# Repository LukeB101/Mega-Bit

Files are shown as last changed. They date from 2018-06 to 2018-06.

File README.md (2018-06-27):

# Mega-Bit
Imperial College London Electrical and Electronic Engineering 3rd year project for the Micro:Bit community

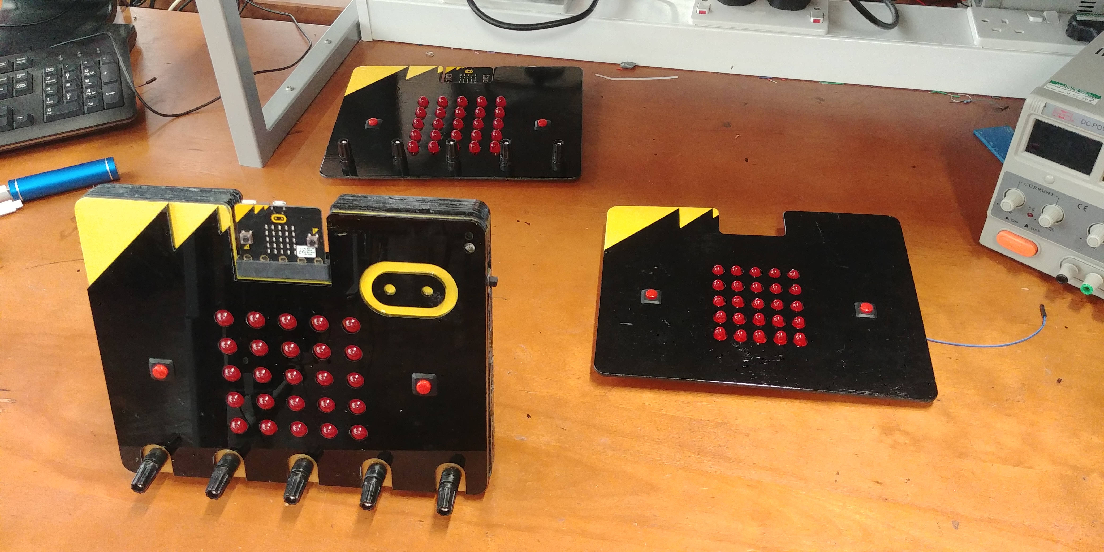
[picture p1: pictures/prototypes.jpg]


The project aim was to create a teaching aid to assist with using the BBC micro:bit to teach programming in schools. To do this it must replicate all of the student's work on a larger scale for the whole class to see. It should do this with no impact on the student's code, simply plug the student's micro:bit in and watch!

## Repository structure:

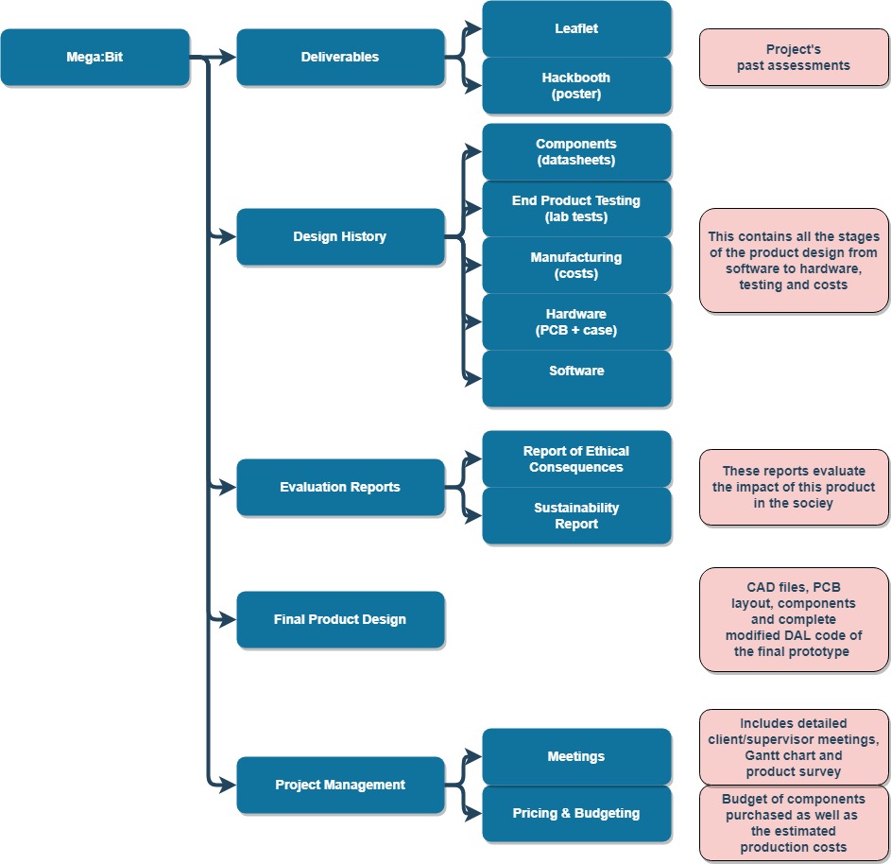
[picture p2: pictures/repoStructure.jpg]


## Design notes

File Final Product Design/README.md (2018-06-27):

This folder contains all files used in the final design. This includes CAD files, component cost breakdown and a complete modified-DAL.

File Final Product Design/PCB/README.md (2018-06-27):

Final PCB designs

Files are duplicates from [Design History  /  Hardware  /  PCB  /  MEGABIT FINAL PCB](https://github.com/LukeB101/Mega-Bit/tree/master/Design%20History/Hardware/PCB/MEGABIT%20FINAL%20PCB)

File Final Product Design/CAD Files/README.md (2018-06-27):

All files to replicate our 3D acrylic case.

Files are duplicates from [Design History  /  Hardware  /  Prototype Modelling  /  Acrylic 3D Final Prototype](https://github.com/LukeB101/Mega-Bit/tree/master/Design%20History/Hardware/Prototype%20Modelling/Acrylic%203D%20Final%20Prototype)

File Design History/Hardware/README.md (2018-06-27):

The hardware of this project is split into two categories; the PCB and the prototype modelling of the mega:bit case.

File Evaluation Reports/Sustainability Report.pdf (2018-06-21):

## Sustainability Report

Aim

This report aims to measure the social and environmental impact of the mega:bit and address future goals and areas of improvement in this area.

Environmental Impact

Environmental consciousness in the production, distribution and subsequent usage of mega:bit is a crucial concern. It is important to ensure that the usage of power, materials and resources in creating this product is justified and that it is made in a responsible manner with reduced wastage. However, since mirco:bit is a not-for-profit organization that serves for educational purposes, affordability for every student is also vital. Therefore, a balance must be made in considering low-cost options as well as environmentally friendly methods.

Production Considerations

The mega:bit is designed to be sent to mass production with 5000 units initially with a potential market of 100,000 units. Consequently, it is important to keep it as environmentally-friendly as possible, reducing damaging and unsafe resources. To make the product more sustainable several points were considered when designing it:

- Materials Wastage: Creating the product entirely as a printed PCB would result in copper wastage as there would be some unused space. However, this would be more practical for production and usage as an additional step of complex wiring and assembly would be reduced minimizing human resources. The plastic outer covering will be also mass produced and by keeping the design unchanged a single mold will be used reducing cost as well as metal wastage.
- Shipping: Although outsourcing production of PCBs and plastic molds is greatly cheaper, rooting manufacturing in the UK is more sustainable. This reduces the carbon footprint associated with cargo shipping from overseas massively. The quotes prices in the UK were checked to be within the preplanned budget.
- Recyclable Materials: The plastic case will be made from a thermoplastic, ¹ which is in nature recyclable. PCBs are also recycled by certain companies.

1
“3 Words: Recyclable Thermoset Plastics.” Nanalyze, 23 Feb. 2017, www.nanalyze.com/2017/01/recyclable-thermoset-plastics/. (http://www.nanalyze.com/2017/01/recyclable-thermoset-plastics/)

Product Usage Considerations

It is also important to ensure power consumption is minimal when mega:bit is used in schools.

- Power Options: In order to reduce wastage with non-rechargeable batteries, mega:bit offers powering with USB ports (portable chargers) or directly connecting to power sockets. To ensure teachers have flexibility in power options, 9V battery port is also included. However, they will be informed in the instruction manual to dispose used batteries responsibly.
- Components Choices: Power efficiency was taken into account in the product design and component choices. For example, a Buck converter was chosen for stepping down voltage instead of a linear regulator due to lower power consumption.
- Long-term Usage: Mega:bit is designed to be robust and durable in a classroom set-up without need for constant replacement. The outer plastic case protects the product from damage from handling by children and falls.

Areas for Improvement

- Recycled Plastic: In the subsequent productions, the larger number of units manufactured might reduce costs such as prices of components due to economies of scale. This could give some leverage to invest in using recycled plastic instead for the outer case.

Social Impact

The micro:bit foundation has a leading role to play in kindling interest in coding amongst children and developing a generation of tech pioneers. Mega:bit will serve a major role in enabling this process by enhancing the learning experience for children and being an effective companion for teacher to create a stimulating learning environment.

Educational Benefits

- Promotes Collaboration: Micro:bit is already being used by thousands of students in the classroom but the mega:bit allows for easy demonstration and sharing of work and ideas among children. This fosters teamwork and the quality of learning from one another.

Inclusion Benefits

- Cater to Special Needs: Beyond being used as a demonstration tool, individuals with special needs can use mega:bit as a complementary tool with their micro:bit. The larger display helps those with partial sight or low vision to code more easily ensuring micro:bit remains an inclusive device for coding.

Future Work

- Haptic Feedback: A possible extension discussed with the client was having haptic feedback. Instead of LEDs, tactile buttons can be configured to enable micro:bit to be used in existing coding programs for the blind.

Conclusion

The mega:bit reinforces micro:bit's position as a useful and inclusive educational tool for computer education. The Micro:bit Educational Foundation has had massive positive impact globally on teaching coding and is continuing to expand in developing countries. The mega:bit would be a versatile tool that would complement and enhance the learning process with the micro;bit reaping more benefits. In future releases, there could be more research into using recycled materials and reducing carbon footprint in an affordable manner.

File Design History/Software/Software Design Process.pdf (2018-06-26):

# Software Design Process

## Objective

Create a method to display student's code from their micro:bit onto a larger mega:bit for demonstration without affecting the micro:bit's performance. This must be done while taking into account the sensors and interactions with additional features such as radio communication. This has to be implemented in a manner such that any student's work can be displayed simply onto the mega:bit's LED matrix without need for additional coding or soldering from the teacher or student.

## Design Context and Software Stack

Several layers exist to translate the user code down to the hardware level. Each ‘sits’ on the top of the next and is procedurally stepped down to the hardware control. However, in some cases, mbed, DAL, and microPython can access the hardware directly. We will concentrate on the online MakeCode editor which differs from the diagram to the left. Instead of the MicroPython layer there are two different layers which connect the user code to the DAL which are

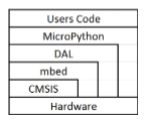
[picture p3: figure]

called the 'pxt-microbit' and 'microbit' layers. Examples of code being translated through the software stack are at Appendix A.

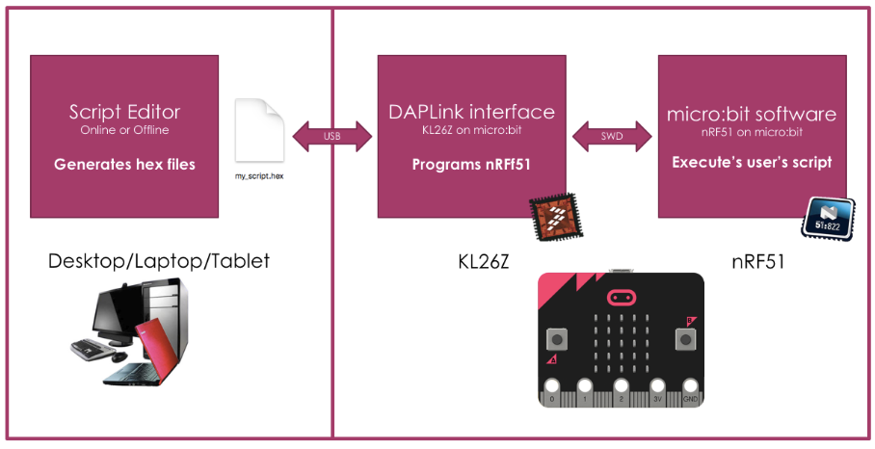
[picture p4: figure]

The micro:bit runtime or device abstraction layer (DAL) contains all the hardware drivers for the micro:bit such as display, radio etc and runtime mechanisms that allow flexible programming of the micro:bit. The script editor generates the .hex files which are then uploaded to the micro:bit to be programmed and executed. The script editor combines the user code with the DAL to form the .hex files. We will insert our code here as it will apply to all user code formats.

## Design Selection Process

1) Accessibility Pin: One of the GPIO pins (p12) is a marked as a ‘reserved accessibility pin’ which by default is not accessible to the user. This was created to leave the Micro:Bit Foundation the option for expansion modules. The theory was for any future peripherals which required data communication this pin would provide a UART connection for data transfer. The Mega:Bit suits this function perfectly.
2) Neopixels: These are addressable multicoloured LEDs that are supported by the micro:bit neopixel library. They can be attached simply with 3 crocodile clip connections for data input, power and ground. A large number of neopixels cannot be powered by the micro:bit and need to be powered externally. The brightness of every LED can be adjusted independently in the software. These could be used for the mega:bit's display however they require strict timings which would require the use of interrupts. This has the potential to interfere with other low level activity on the micro:bit which also require strict timings and interrupts (for example the Bluetooth and RF radios).
3) I2C: The larger LED matrix could be controlled via I2C communication. An I2C LED display driver could be used to drive a matrix of LEDs which would be simple to implement as I2C is natively supported. I2C also has less strict timing requirements as the master can drive the clock at any frequency it would like (up to 400 kHz) in fact if the master has background tasks to do while transmitting it can 'stretch' the clock signal to greater allow for these. I2C bus utilisation must be investigated as we do not want to interfere with the other sensors on the I2C bus.
4) USB: Possibly provide two-way communication to control the mega:bit through the USB port or ‘clone’ the code onto the mega:bit. Two-way communication through the USB port is not feasible but cloning the code potentially is. The code is stored in a particular place in the on-chip memory which could be read and copied to the mega:bit. This however requires a level of 'intelligence' on the mega:bit side, for instance like a Raspberry Pi. This would obviously add cost and be more expensive than the alternative methods.

## Execution of I2C Method

The I2C method was chosen as it provides the simplest and cleanest solution however the accessibility pin may still be used to provide a handshake to confirm when the micro:bit is plugged into the mega:bit.

Micro:Bit I2C Functionality

The I2C communication standard allows for many I2C slaves. The micro:bit has two existing devices on the I2C bus, the compass and accelerometer, we must ensure our use of the bus does not affect the existing functionality. This is done by ensuring there are no addresses clashes with the existing sensors. (See Appendix B for I2C address selection)

It is important to note that the 7-bit addresses found in the device datasheets have to translated with a binary shift left as an 8-bit address is to be used with the micro:bit. For example, the adafruit HT16K33 backpack has an address 0x70, that must be translated to 0xE0.

Driving LED Matrix using I2C

Components used: Adafruit 0.8" 8x8 Matrix with HT16K33 Backpack, micro:bit edge connector.

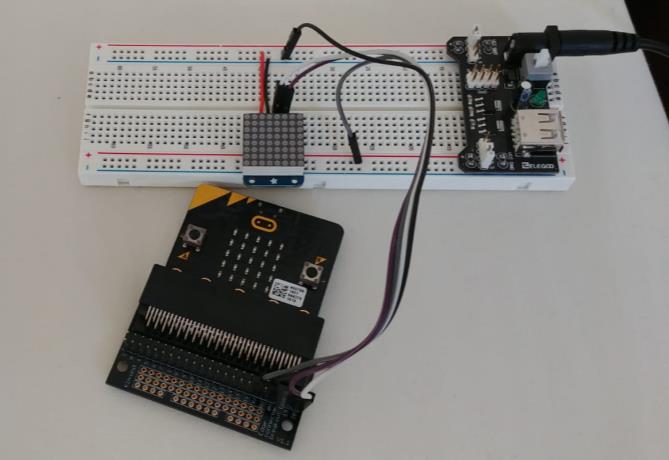
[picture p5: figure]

An Adafruit backpack¹ was used for convenience as a comprehensive library exists. This means we can quickly and easily create a proof of concept before moving on to creating our own PCBs. The I2C pins of the micro:bit, pin 19 and 20 are accessed using an edge connector. The connections are made as follows:

Microbit Pin | Backpack Pin
Pin 19 | SCA
Pin 20 | SDA
GND | GND
3V | VCC+

The DAL (Device Abstraction Layer) code was modified in order to implement the communication with the I2C external LED matrix.

The listing below shows the initialisation of the global variables needed to set up the LED display. The general structure of the code to interface with the HT16K33 LED driver was translated to C++ from a Python library for the backpack

2

1 Microbit Playground. (2016). Control a 8x8 LED matrix with an I2C backpack on the microbit. [online] Available at: https://microbit-playground.co.uk/components/8x8-matrix-HT16K33-microbit.

2
https://bitbucket.org/thesheep/microbitht16k33/src/a5b7961f0b57ba226ab98edc2c5f8d95d8954d00/ht16k33.py

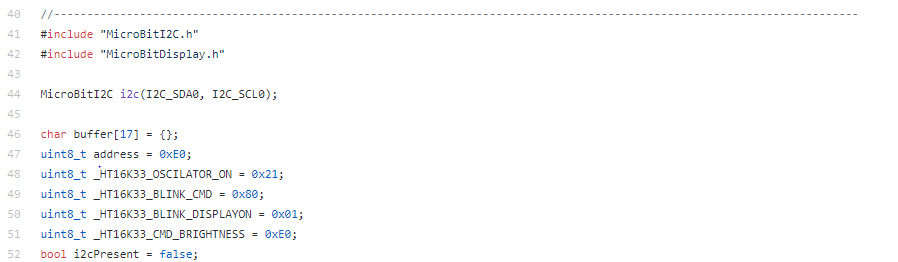
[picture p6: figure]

Configuring Display on LED Matrix

The listing below shows the initialisation process of the LED display. After having checked whether the I2C ports are being used (i.e. if a mega:bit is connected), the buffer is filled with zeroes, the oscillator is turned on and an initial blink rate and brightness are set.

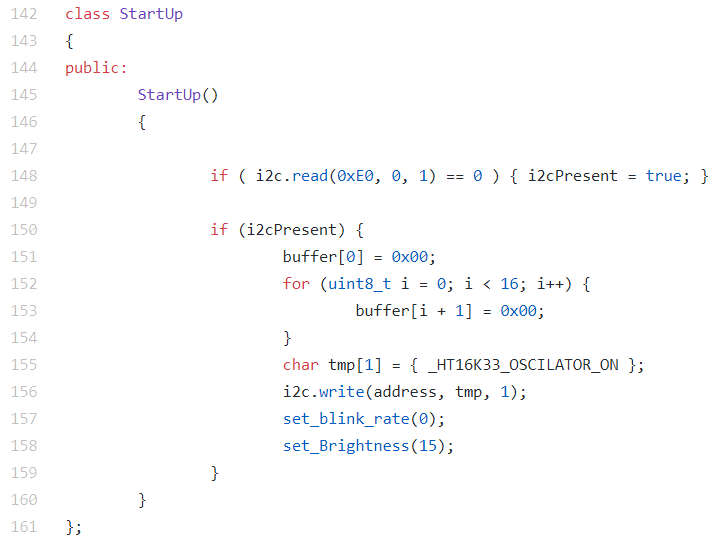
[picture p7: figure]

Eight main display control functions have been implemented:

Function | Description
set_blink_rate | Sets the blink rate of the display
set_Brightness | Sets the brightness of the display
update_Brightness | Updates the brightness of the display to a new value
fill | Fills the display
initialise | Initialises the display (similar to the StartUp class above)
_pixel | Plots single pixels on the matrix
pixel | Converts x coordinates and calls _pixel function
bufferClear | Clears the buffer

Replicating All Functionality

The micro:bit display is updated to match a 'buffer' which stores the image/text to be displayed. It works on an interrupt basis and is updated several times per second. The I2C display holds the previous state so does not need to be constantly updated, this would also take up unnecessary processing power and bus utilisation. Therefore, we only update the I2C display whenever the buffer is modified, this is the most efficient way of implementing the code.

## Additional Work

After successfully implementing the Adafruit LED backpack we moved to developing custom PCBs, these used the same HT16K33 chips so the software was unaffected.

Handshake
A simple handshake was then implemented; using a 555 timer a 1kHz square wave is supplied to the accessibility pin of the micro:bit. When the microbit is powered up, it senses the presence of the square wave on its accessibility pin. If there is no 1kHz signal, the micro:bit will function as per usual. However, if it is present, a boolean variable is set to true and thus whenever the buffer is edited, through an if statement, the I2C display is also updated. This means that extra processing power is not used to send I2C commands when the micro:bit is not plugged into the mega:bit. This can also be adapted to function as an identifier, different signal frequencies indicating different peripherals.

IS31FL3737
As explained in the hardware section of the GitHub repository (found at https://github.com/LukeB101/Mega-Bit/tree/master/Design%20History/Hardware) after implementing all functionality described above, we investigated using a different chip which runs off 3.3V rather than 5V and allows for other functionality. This chip requires different code which is still under development as the custom PCB did not arrive in time to write the software before university deadlines. This software will be developed outside of this university project.

Further References:

"Microbit-RTCC-MCP7941X - Program To Interface Bbc Microbit To A MCP79410... | Mbed".
Os.Mbed.Com, https://os.mbed.com/users/euxton/code/microbit-RTCC-MCP7941X/file/92208e3aae5a/main.cpp/.

"Driving Adafruit I2C 8X8 LED Matrices With The BBC Micro:Bit". Smythe-Consulting.Com, 2017, http://www.smythe-consulting.com/2017/03/driving-adafruit-i2c-8x8-led-matrices.html.

Micro:Bit DAL: https://github.com/lancaster-university/microbit-dal

Micro:Bit Software Stack: https://github.com/lancaster-university

## Appendix A

Using the JavaScript editor at makecode.microbit.org

The different headings show different layers in the software stack

JavaScript

Taking the code:

basic.showNumber(0)

Pxt-microbit
This is first translated by pxt-microbit/libs/core/basic | void | showNumber(int | value, | int | interval =
150) {

https://github.com/Microsoft/pxt-microbit/blob/master/libs/core/basic.cpp#L19

(as number does not need scroll) in to: | uBit.display.printChar(t.charAt(0), interval * 5);
uBit is defined in pxt.cpp: | MicroBit | uBit;

https://github.com/Microsoft/pxt-microbit/blob/master/libs/core/pxt.cpp#L4

microbit
This is passed to the DAL wrapper where the display class is defined: MicroBitDisplay
display;

https://github.com/lancaster-university/microbit/blob/master/inc/MicroBit.h#L111

microbit-DAL
This is passed to the DAL where the printChar function is defined:

https://github.com/lancaster-university/microbit-dal/blob/master/source/drivers/MicroBitDisplay.cpp#L606 (https://github.com/lancaster-university/microbit-dal/blob/master/source/drivers/MicroBitDisplay.cpp)

The printChar function calls the printCharAsync function: | this->printCharAsync(c,
delay);

Which is defined here:

https://github.com/lancaster-university/microbit-dal/blob/master/source/drivers/MicroBitDisplay.cpp#L481 (https://github.com/lancaster-university/microbit-dal/blob/master/source/drivers/MicroBitDisplay.cpp)

The printCharAsync function calls the image.print function: | image.print(c, 0, 0);

Which is defined here:

https://github.com/lancaster-university/microbit-dal/blob/master/source/types/MicroBitImage.cpp#L572 (https://github.com/lancaster-university/microbit-dal/blob/master/source/types/MicroBitImage.cpp#L572)

and calls: this->getBitmap()[y1*getWidth()+x1] = (v & (0x10 >> col)) ? 255 : 0;

Conclusion
From this and other examples it is clear our software edits must be done within the MicroBitImage.cpp file since this is at the lowest level and deals with the buffer.

## Appendix B

## Adafruit I2C Sensor Addresses

To investigate the possibility of I2C address clashes a table was created displaying I2C sensors on the market and their addresses. Adafruit and SparkFun were chosen specifically as our client indicated any sensors used in schools would be used in a breakout board package and that these are the market leaders.

The table below and the i2c-addresses.pdf file show the range of I2C addresses used in their sensors. This data will be used to ensure the Mega:Bit does not clash with many, if any, other devices.

For the IS31FL3737 the address 0xAA was chosen, in 7bit format that is 0x55 which is taken by only one device which has 7 selectable address therefore does not pose any major risk of device clashes.

Sensor | I2C address | Webpage link
TCA9548A I2C Multiplexer | 0x70 (but can be adjusted from 0x70 to 0x77) | https://www.adafruit.com/product/27 17 (https://www.adafruit.com/product/2717)
Adafruit I2C Controlled + Keypad Shield Kit for 16x2 LCD | 0x20 | https://www.adafruit.com/product/71 5 (https://www.adafruit.com/product/715)
FLORA Accelerometer/Compass Sensor - LSM303 - v1.0 | 0x32 & 0x3C | https://www.adafruit.com/product/12 47 (https://www.adafruit.com/product/1247)
Flora Lux Sensor - TSL2561 Light Sensor - v1.0 | 0x39, 0x29, 0x49 | https://www.adafruit.com/product/12 46 (https://www.adafruit.com/product/1246)
MCP9808 High Accuracy I2C Temperature Sensor Breakout Board | Uses any I2C address from 0x18 thru 0x1F | https://www.adafruit.com/product/17 82 (https://www.adafruit.com/product/1782)
Adafruit HTU21D-F Temperature & Humidity Sensor Breakout Board | 0x40 | https://www.adafruit.com/product/18 99 (https://www.adafruit.com/product/1899)
Adafruit Blue&White 16x2 LCD+Keypad Kit for Raspberry Pi | 0x20 | https://www.adafruit.com/product/11 15 (https://www.adafruit.com/product/1115)

LCD Shield Kit w/ 16x2 Character Display - Only 2 pins used! - BLUE AND WHITE | 0x20 | https://www.adafruit.com/product/77 2 (https://www.adafruit.com/product/772)
RGB LCD Shield Kit w/ 16x2 Character Display - Only 2 pins used! - NEGATIVE DISPLAY | 0x20 | https://www.adafruit.com/product/71 4 (https://www.adafruit.com/product/714)
MaximIntegrated DS1307 – real time clock | 0x68
Melexis MLX90614 – infrarred thermometer | 0x5A
FreeScale MMA8452Q 3-Axis Accelerometer | 0x1C, 0x1D
AKM AK9753 IR Sensor | 0x64H, 0x65H, 0x66H
AM2315 - Encased I2C Temperature/Humidity Sensor | 0x5C | https://www.adafruit.com/product/26 51 (https://www.adafruit.com/product/2651)
Adafruit BMP280 I2C or SPI Barometric Pressure & Altitude Sensor | SPI avoid i2c address collisions | https://www.adafruit.com/product/26 51 (https://www.adafruit.com/product/2651)
Adafruit Mini 8x8 LED Matrix w/I2C Backpack -Ultra Bright White | between 0x70-0x73 | https://www.adafruit.com/product/10 80 (https://www.adafruit.com/product/1080)
Adafruit Bicolor LED Square Pixel Matrix with I2C Backpack | between 0x70-0x77 | https://www.adafruit.com/product/90 2 (https://www.adafruit.com/product/902)
Adafruit 16-Channel 12-bit PWM/Servo Driver - I2C interface - PCA9685 | between 0x40-0x7F | https://www.adafruit.com/product/81 5 (https://www.adafruit.com/product/815)
Adafruit 16-Channel 12-bit PWM/Servo Shield - I2C interface | between 0x60-0x80 | https://www.adafruit.com/product/14 11 (https://www.adafruit.com/product/1411)
ADXL345 - Triple-Axis Accelerometer (+-2g/4g/8g/16g) w/ I2C/SPI | 0x53 | https://www.adafruit.com/product/12 31 (https://www.adafruit.com/product/1231)

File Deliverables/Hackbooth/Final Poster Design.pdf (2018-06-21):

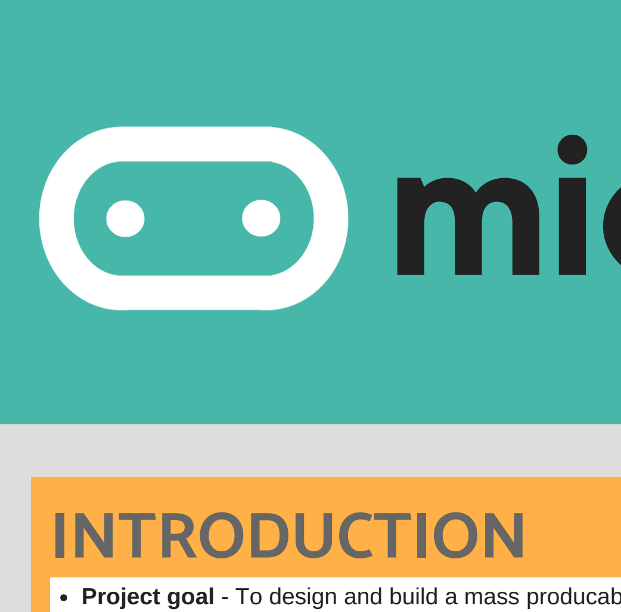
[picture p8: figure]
INTRODUCTION

# micro:bit to mega:bit

# A TEACHING TOOL TO ENHANCE COMPUTING EDUCATION IN SCHOOLS

</>

Project goal - To design and build a mass producable teaching aid for schools to help with incorporating micro:bit into computing lessons.

Current Problem- The micro:bit is a pocket-sized handheld computer with a programmable LED display. While the small micro:bit is great for coding, teachers find it difficult to demonstrate student's work to the whole class.

Haptic Feedback: Replacing the LED matrix with tactile feedback to enable visually impaired students to use the micro:bit RGB LEDs: Switch between colours of the LED matrix for improved learning experience
Foldable Handles and stand: For easy use and storage for teachers
Changing the I2C address: Enable usage of all peripherals without possibility of I2C addresses conflicting

# FUTURE WORK

# BACKGROUND

Our client, Micro:bit Educational Foundation, is a not-for-profit organisation that created the micro:bit to encourage digital creativity and develop a new generation of tech pioneers.

It is rapidly expanding globally and being used in diverse settings such as refugee camps in Greece.

1 Million Students | 22 Countries

While designing the mega:bit, important client criteria and requirements had to be taken into account in order to make a device that is easy to handle for the teacher and is suitable for use in schools.

1) Ergonomic Design
2) Easy to Use
3) Safe

# CLIENT CRITERIA

Display: The mega:bit replicates the form factor of the micro:bit with a 5x5 LED display, two push buttons and edge connectors at the bottom, but is much larger allowing the whole class to see the operation of the code.
Whenever there is a change in the LED display of the micro:bit, the larger LED matrix of the micro:bit is updated via I2C communication.

Seamless Integration: The student's micro:bit is plugged into the top of the mega:bit without the need for any additional soldering or coding from the user's side which allows for easy use.

Detection of Micro:bit: A "handshake" between the mega:bit and micro:bit allows detection for when a micro:bit is plugged in.

Battery Indicator: Features such as battery level indicators and a reset button are also present for convenience.

# SOLUTION

# PRODUCTION

The mega:bit will be released in batches in the UK first. It will then expand globally as the micro:bit community grows.

Unit Price | Initial Volume

£50

mega:bit will be mass-produced in two parts: a PCB and a plastic outer casing. A medium sized PCB is used as it is low cost in large numbers. To ensure robustness in a classroom environment, the casing will conceal and protect the electronic components from droppage and static.

Potential Market

5000
units | units

100k

micro:bit official webpage: microbit.org
prototyping: https://www.adafruit.com/product/870
battery indicator: http://www.instructables.com/id/9v-battery-status-indicator-circuit/

# BIBLIOGRAPHY

Microbit.org. (n.d) Micro:bit Educational Foundation. [online] Available at: http://www.microbit.org/.
Industries, A. (2018). Adafruit Mini 8x8 LED Matrix w/I2C Backpack -Red. [online] Adafruit.com.
Available at: https://www.adafruit.com/product/870.
Instructables.com. (2012). 9v Battery Status Indicator Circuit. [online] Available at: http://www.instructables.com/id/9v-battery-status-indicator-circuit/.
GitHub. (n.d.). BBC micro:bit. [online]
Available at: https://github.com/bbcmicrobit.

Hardware: Price, S., Boskovic, K.,Christodoulou, A., Lu Chen, W. Software: Bussell, L., Carrani, J., Mathivanan, A.
Academic Supervisor: Stott, E.
Client Supervisor: Austin, J.
Department of Electrical and Electrical Engineering, Imperial College London SW7 2AZ

More powerful LED driver, able to drive up to 144 LEDs and provide individual brightness USB or 9V Battery power =
Buck 3.3V, linear regulator 5V Battery indicator

Final 100 x 120 PCB, 10 mm LEDs

## Final PCB Design

Stage 1 | Stage 2 | Stage 3 | Stage 4

62 x 57mm PCB size, 3 mm LEDs

## Test I2C Functionality

90 degree micro:bit edge
connector
LED matrix controlled by LED driver
Power supply: 5V USB followed by 3.3V linear regulator

### 1. I2C option – use micro:bit’s I2C

serial interface to connect mega:bit as a slave device

### 2. Accessibility pin option – Use pin

reserved for transfering data using UART
Result: I2C chosen as it is simple and effective. Other I2C devices can still be connected in parallel

## Data Transfer Methods

2 LED PWM drivers to enable LED brightness control

### 4 x 1.5V battery - buck to 3.3V

96 x 66mm PCB size, 10 mm LEDs

## Individual Brightness

Added possibility to choose between USB and batteries. 9V battery - 5V linear regulator +3.3V linear regulator

### 2 x 1.5V battery - boost to 5V

+3.3V linear regulator

100 x 74mm PCB size, 8 mm LEDs

## Powering Options

### 1. Alter the print functions in the

DAL to include mega:bit display print code via I2C

### 2. Take into account the mega:bit’s

LED matrix driver dimensions by coding correct image bitmaps

### 3. Mega:bit LED matrix updated

every time there is a change in the micro:bit’s display
Result: Single letters can be displayed on matrix

## I2C Implementation

### 1. Alter animation mode in the DAL

to allow for functions such as scroll and rotation of text.

### 2. Enable control of individual LED

brightness on the mega:bit Result: All characters, images and scrolling of text can be displayed on the mega:bit with specified brightness

## Animation Mode

Use accessibility pin to detect when micro:bit is connected with a predefined signal that the micro:bit searches for on startup.

### micro:bit Detection

# Software

# Hardware

# Final Product

Rev. 1 | Physical model

# Rev. 2

Buttons

micro:bit Slot

Handle

Plastic Front Cover

PCB

Plastic Back Cover

Banana Connectors

LED Matrix

# Block Diagram

# Prototype

4) Reliable
5) Sustainable
6) Cost-Effective

Plastic Front & Back Case
PCB
Assembled by the end user with simple screws
Instruction Manual included

## mega:bit

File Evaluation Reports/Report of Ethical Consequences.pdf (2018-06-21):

## Report of Ethical Consequences

Aim

The aim of this report is to examine the ethical considerations associated with the design, manufacturing, and marketing of the mega:bit product. Ethics in production and marketing of a product are of great significance as non-compliance with ethical principles are undesirable and would harm the company's reputation.

The micro:bit Foundation

The micro:bit Foundation is a collaboration of more than 30 international organisations, pioneering start-ups and transformative education organisations. It is a not-for-profit organisation with an aim to make computing more interesting, and accessible to help inspire every child to start coding and make a new generation of tech pioneers. The micro:bit is a pocket-sized programmable computer with motion detection, a built-in compass and Bluetooth technology that has been introduced to over 500 schools in the UK to serve this aim.¹

Micro:bit Foundation's Mission

The mission of the Foundation includes the following²
:
- Enable and inspire all children to participate in the digital world, with a particular focus on girls and those from disadvantaged backgrounds.
- Make micro:bit the easiest and most effective learning tool for digital skills and creativity.
- Work in collaboration with educators to create and curate exceptional curriculum materials, training programs and resources.
- Build and support communities of educators and partners to remove the barriers to learning digital skills.

Furthermore, the Micro:Bit Foundation is also helping change the attitude of many children towards computing by making coding and technology more accessible to them through its ‘Make it Digital’ initiative³ and encouraging more girls into computing subjects. Research conducted after over 1 million devices had already been deployed has shown that⁴
:
- 90% of students said the micro:bit showed them that anyone can code.
- 86% of students said the micro:bit made Computer Science more interesting.

1 BBC. (n.d.). Make It Digital - The BBC micro:bit - BBC. [online] Available at: http://www.bbc.co.uk/programmes/articles/4hVG2Br1W1LKCmw8nSm9WnQ/the-bbc-micro-bit. 2 Microbit.org. (n.d.). About. [online] Available at: http://microbit.org/about/.
3 Microbit.org. (n.d.). Micro:bit Educational Foundation is here!. [online] Available at: http://microbit.org/en/news/news-microbit-foundation/.
4 Microbit.org. (n.d.). Let's make learning with technology fun!. [online] Available at: http://microbit.org/teach/.

- 70% more girls said they would choose Computing as a school subject after using the micro:bit.
- 85% of teachers agree it has made ICT/Computer Science more enjoyable for their students.
- Half of teachers who’ve used the micro:bit say they now feel more confident as a teacher, particularly those who say they’re not very confident in teaching Computing.

To ensure the micro:bit’s aim continues so that more children get involved in coding, mega:bit was designed to further enhance the teaching experience and make lessons more fun and involving for students.

The mega:bit

The mega:bit is a teaching aid for use with the micro:bit. By simply plugging in a student's micro:bit it displays their work on a larger scale. It is designed to allow easy demonstration of students’ work to the whole class and increase the interactive participation of students when using the micro:bit. As a result, the production of the mega:bit will enable the Micro:Bit Foundation to grow responsibly by still fitting into the Foundation’s aim to encourage students, and especially girls, to get more involved in STEM subjects.

Ethical Considerations relating to mega:bit

To fulfill the mission of the Micro:Bit Foundation, the mega:bit has been designed to meet the ethical requirements associated with the environment in which it will be used, i.e. in schools. These are high product quality, safety, ethical pricing strategy and marketing transparency.

Product quality and safety

Following the successful design of the micro:bit, the mega:bit replicates this design making it safe to use in schools. The mega:bit has been rigorously tested to ensure this. The product is also ergonomic as it is designed to be lightweight, sleek and robust. Furthermore, its features meet the specific teacher requirements which were identified through a survey conducted in the teacher channel of the micro:bit community. Finally, the product design comprises a handle for people with disabilities to ensure increased accessibility for users.

Under a limited budget, an important ethical concern was how to design and build a cost efficient product without reducing its quality. This was achieved through thorough research on components and materials to be used and three PCB revisions to test and select the design options to be implemented in the final design and prototype.

Ethical Pricing

The price of the megabit is £50, making it affordable to an average school. The price reflects the cost of production of the mega:bit and includes an added profit margin of £28. This profit margin will primarily be taken by the manufacturing and fabrication companies leaving a much small profit for the Foundation. The potential profits of the mega:bit are reinvested within the micro:bit community aiming at further expansion and school outreach. The micro:bit foundation will produce and distribute the mega:bit product design through external channels. Thus, the pricing is such as to allow the organization to increase the impact of the micro:bit and mega:bit on teaching computing all around the world.

Involvement in Education

According to sustainability reports from the Foundation’s partners, promoting STEM education is about creating a wider pipeline of talent for the industry and equipping a global workforce with the skills for fulfilling careers⁵
. The aim is to grow the talent pool, increase the opportunities available to women and inspire those who may not otherwise follow a STEM path. Given the extremely positive results obtained after the micro:bit entered schools, introducing the mega:bit to classes will further enhance this. It will also continue to encourage and inspire children to get more involved in STEM subjects by encouraging participation and making the classes more interactive.

5 ARM Corporate Responsibility Report. (2015). [ebook] Cambridge: ARM Holdings plc. Available at: https://www.arm.com/files/pdf/ARM-Corporate-Responsibility-Report-2015.pdf.

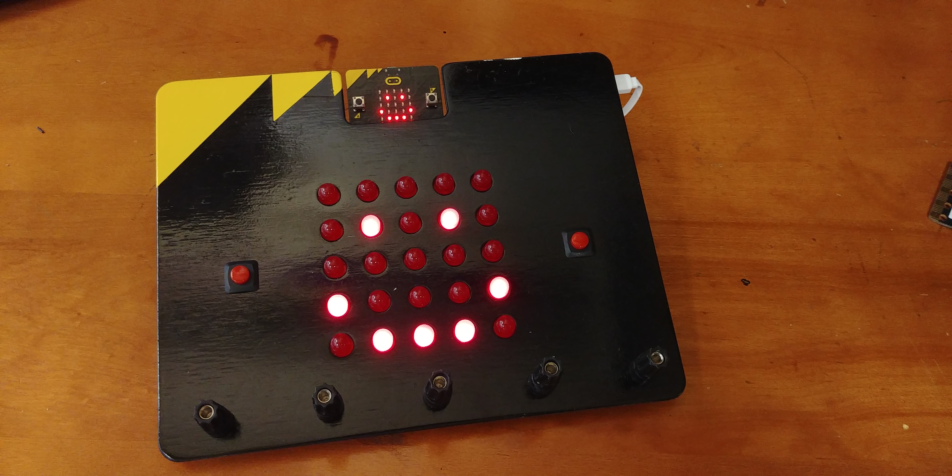
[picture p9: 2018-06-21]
Design History/End Product Testing/Pictures/Megabit proof of concept.jpg

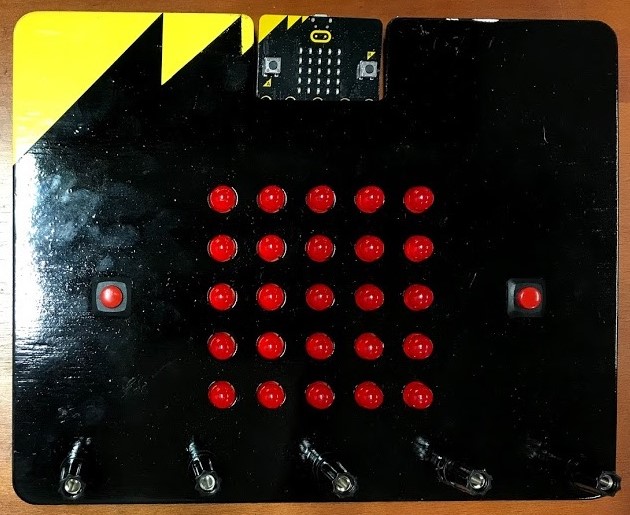
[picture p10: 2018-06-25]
Design History/Hardware/Prototype Modelling/Prototype 2 10mm LEDs/prototype2.jpg

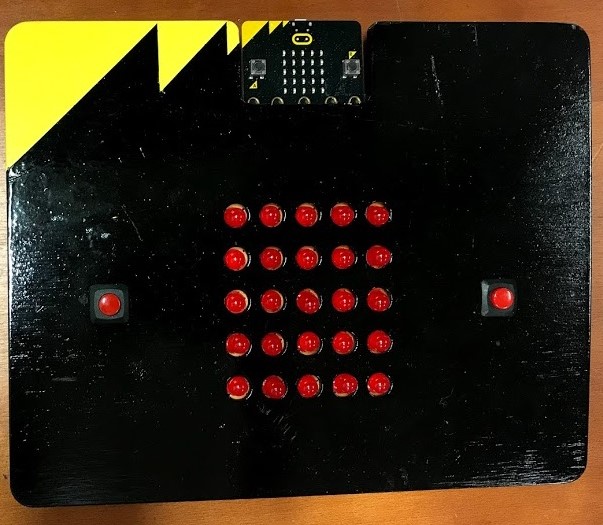
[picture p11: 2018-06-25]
Design History/Hardware/Prototype Modelling/Prototype 1 8mm LEDs/prototype1.jpg

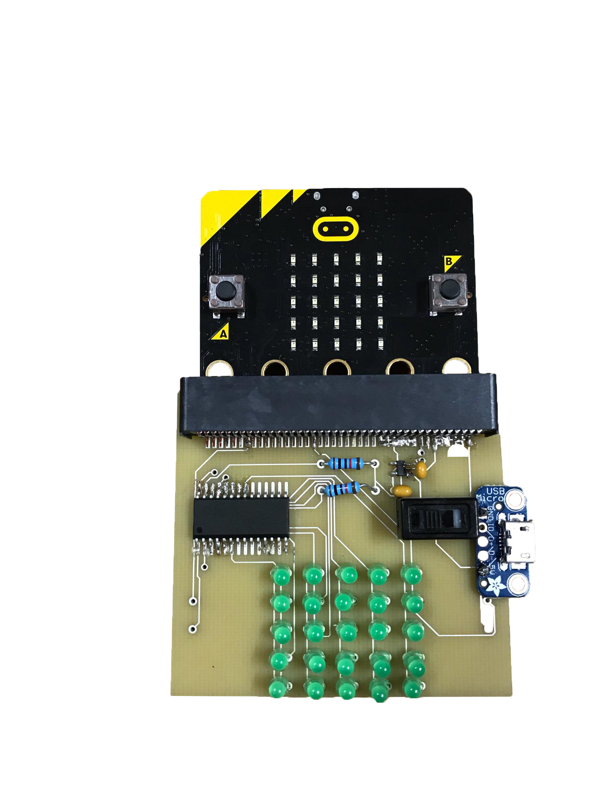
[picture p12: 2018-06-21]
Deliverables/Hackbooth/Poster Illustrations/1st Revision.png

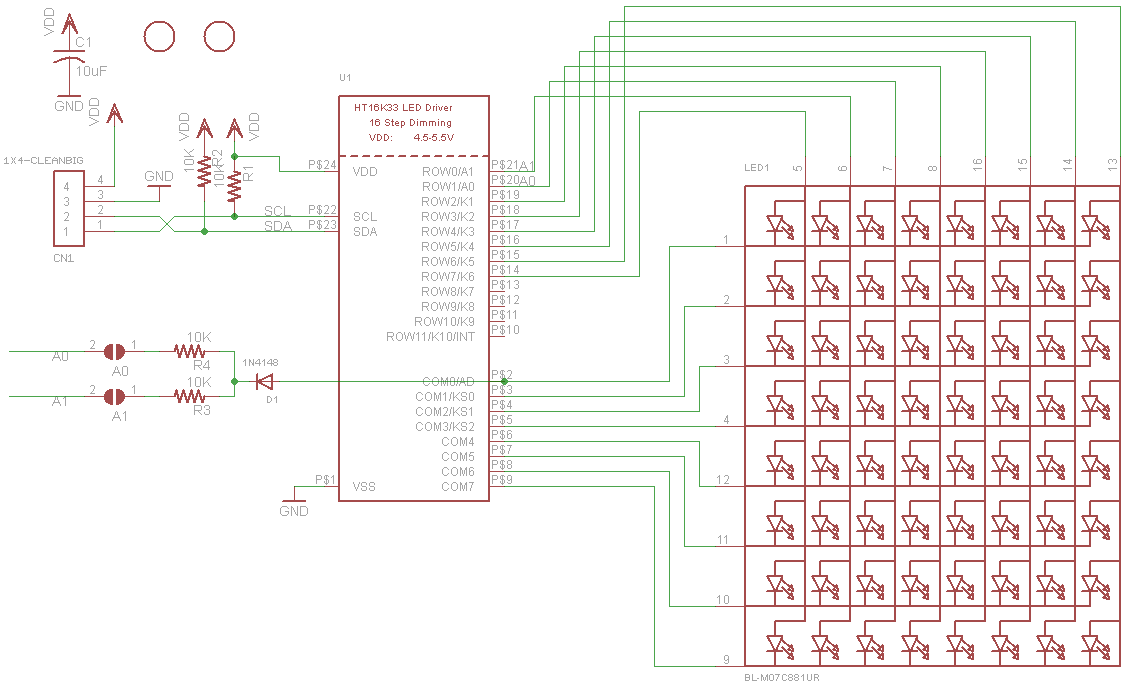
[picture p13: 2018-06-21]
Design History/Components/I2C LED Matrix and Driver/LED Matrix Schematic.png

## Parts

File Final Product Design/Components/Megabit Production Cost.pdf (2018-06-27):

ALL PRICES ARE CONSIDERED FOR BUYING 5000 UNITS (incl. VAT)
1) Components
| Supplier | Quantity | Unit Price | Total Price £ | Quote
UA78M05CDCYR surface mount 5v 500ma linear reg | Mouser | 1 | 0.165 | 0.165 | 5000 quote
ICM7555IPA GENERAL PURPOSE TIMER, 1MHz (555 timer for generating 1khz handshake) | Mouser | 1 | 0.22 | 0.22 | 5000 quote
ISSI IS31FL3737 LED DRIVER | Mouser | 1 | 0.768 | 0.768 | 5000 quote
Regular SPDT switch | EEDSTORE | 1 | | 0
Adafruit 1833 USB Micro B Breakout Board | Rapid | 1 | 0.9 | 0.9 | 50 quote
Kingbright L-813SRD/E 10mm Red LED 550mcd | Mouser | 25 | 0.066 | 1.65 | 5000 quote
Banana connectors for megabit | EEDSTORE | 5 | 0.15 | 0.75 | 5000 quote
SCI R13-510A Red Push Button Switch | Rapid | 2 | 0.34 | 0.68 | 50 quote
TC54VN2702ECB713 | Farnell | 1 | 0.288 | 0.288 | 50 quote
Edge connector | Dongguan Yuliang | 1 | 0.65 | 0.65 | 100 quote
Resistors | Mouser | 10 | 0.004 | 0.04 | 5000 quote
Capacitors | Farnell | 10 | 0.0224 | 0.224 | 5000 quote
Total Components Price | | | | 6.335
2) PCB
120mm x 170mm | Cambridge circuit | 1 | 1.05
3) Plastic cover
Front | China Plastic (Production) | 1 | 0.7 | 0.7 | 5000
Back | China Plastic (Production) | 1 | 0.7 | 0.7 | 5000
Shipping
4) Delivery
0-1 kg | Myhermes | 1 | 3.29
TOTAL MEGABIT PRODUCTION COST | 12.075

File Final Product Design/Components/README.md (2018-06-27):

Breakdown of component costs for final design

Files are duplicates from [Project Management  /  Pricing and Budgeting](https://github.com/LukeB101/Mega-Bit/tree/master/Project%20Management/Pricing%20and%20Budgeting)

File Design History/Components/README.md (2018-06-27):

In this folder you will find the datasheets of all components used throughout the project.

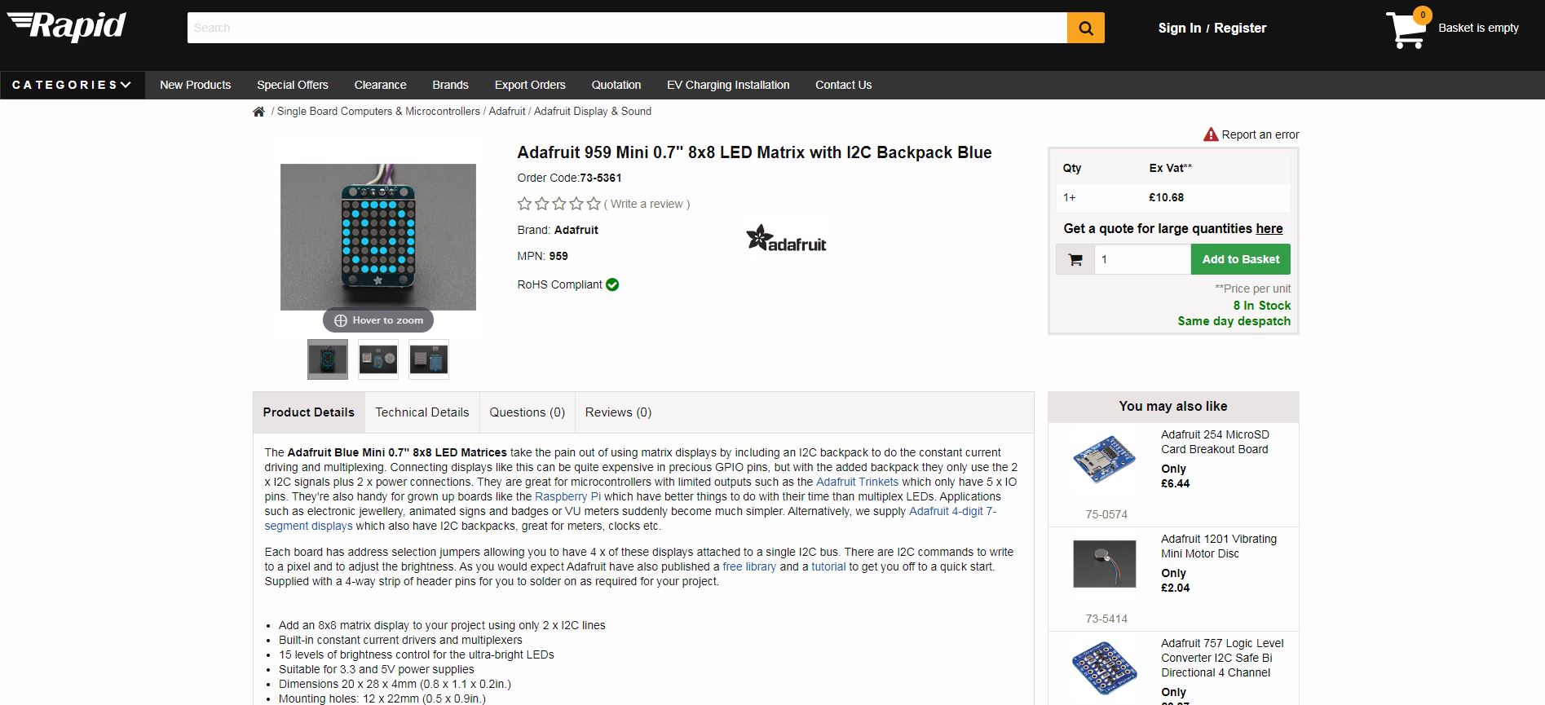
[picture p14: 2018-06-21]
Design History/Components/I2C LED Matrix and Driver/Supplier Order.JPG

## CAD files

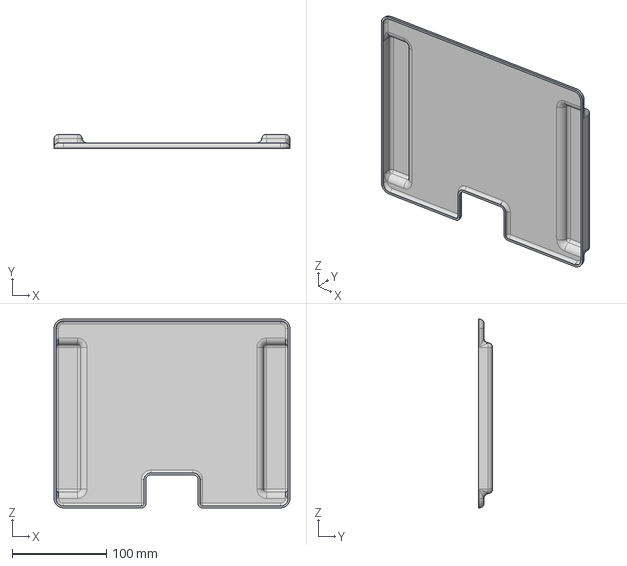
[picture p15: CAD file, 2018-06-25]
Design History/Hardware/Prototype Modelling/Production Product/Production Quote Files/Back.step
250.0 x 15.0 x 200.0 mm

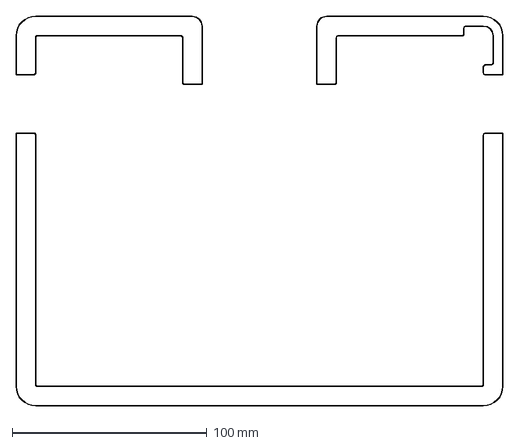
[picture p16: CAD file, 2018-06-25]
Final Product Design/CAD Files/sides.dxf
250.0 x 200.0 mm

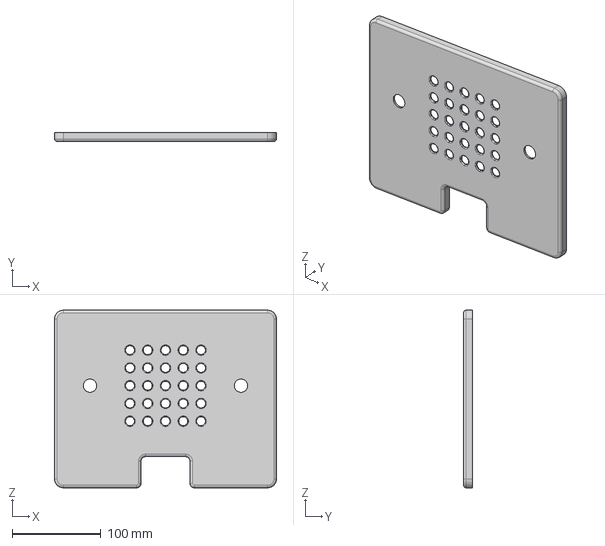
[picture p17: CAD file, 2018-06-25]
Design History/Hardware/Prototype Modelling/Production Product/Production Quote Files/Front.step
250.0 x 10.0 x 200.0 mm

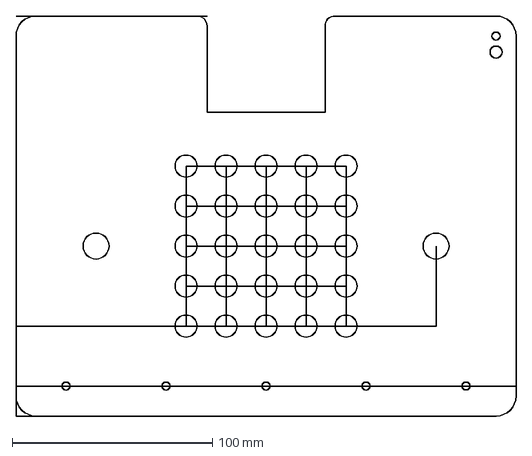
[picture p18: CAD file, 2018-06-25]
Final Product Design/CAD Files/front painted layer.dxf
250.0 x 200.0 mm

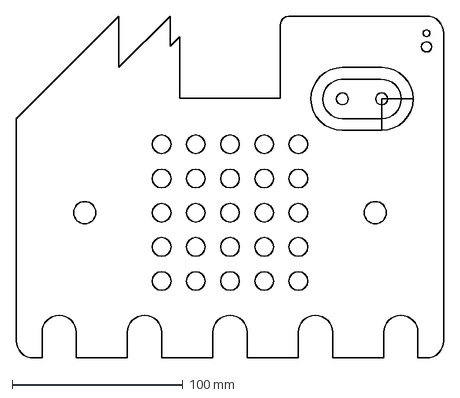
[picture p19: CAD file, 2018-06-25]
Final Product Design/CAD Files/front acrylic cover.dxf
250.0 x 200.1 mm

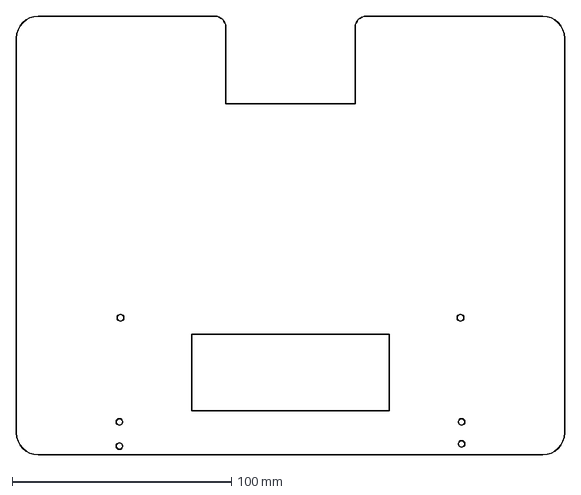
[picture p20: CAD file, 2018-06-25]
Final Product Design/CAD Files/back.dxf
250.0 x 200.0 mm

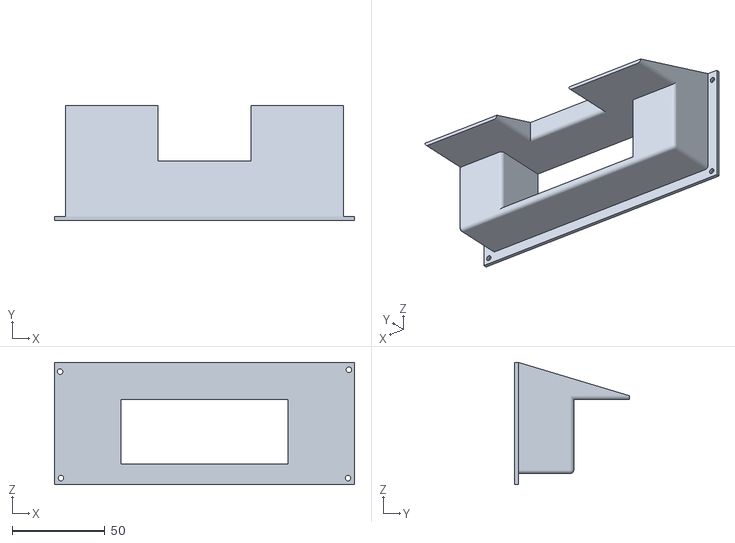
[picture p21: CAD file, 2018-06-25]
Final Product Design/CAD Files/stand.stl
162.0 x 62.0 x 66.0

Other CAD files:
Design History/Hardware/Prototype Modelling/Production Product/Final Design/Megabit Rev1.f3d
Design History/Hardware/Prototype Modelling/Production Product/Production Quote Files/Back.stl
Design History/Hardware/Prototype Modelling/Production Product/Production Quote Files/front.stl

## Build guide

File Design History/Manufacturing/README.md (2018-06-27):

Item | Description
--- | --- 
/Plastic Case Supplier Quotes | Quotes for case production using injection moulding
Manufacturing Considerations.pdf | Brief outline of case requirements
Megabit Production Cost.pdf | Breakdown of final product manufacturing costs

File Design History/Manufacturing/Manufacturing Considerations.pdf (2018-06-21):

## Manufacturing End Product

Concept Design

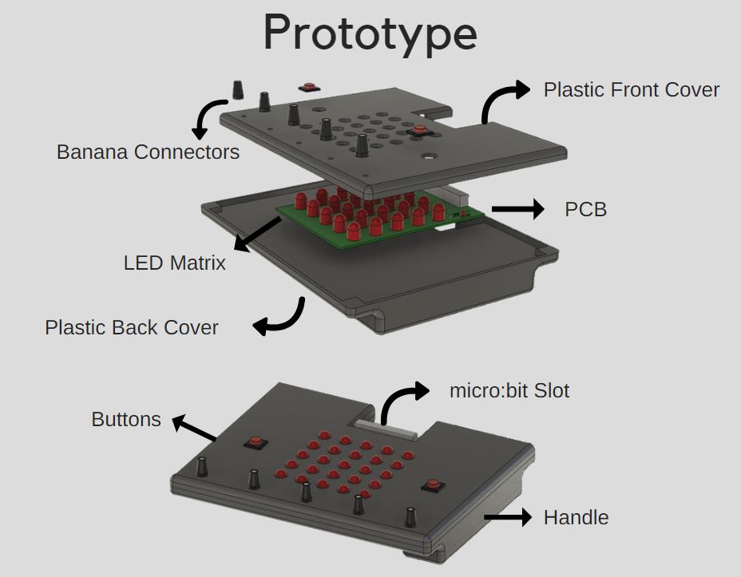
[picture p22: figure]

Plastic External Cover - Requirements

General material expectation would be like that of a children’s product:

- toy- safe
- sturdy
- lightweight
- low cost

However, precise dimensional design is required.

Plastic External Cover - Characteristics

1.Expected life span – 5 years

2.Expected Production Volume – 10,000

3. Target Cost
- Material: Volume of the piece * density of the material * price by weight
- Machine time: The hourly cost of the injection molding machine divided by the number of pieces produced per hour.

- Investment: The amount invested into the tool divided by the number of pieces produced (there are as many ways of calculating this figure as there are customers).
4. Expected temperature range – 15-30°C (room temperature)
5. Exposure to other chemicals
6. Need for dimensional accuracy – must be precise

Manufacturing process

Establish design needs -> Get a quote -> Product designers develop 3D model -> Metal Tooling Device is made -> Plastic is moulded using this tool

UK- Based Supplier Options

- Toolcraft Plastics (Swindon) - https://www.toolcraft.co.uk/toolcraft-plasticsswindon/contact/enquiry-plastic-moulding-antistatic-packaging-vacuum-forming.php (https://www.toolcraft.co.uk/toolcraft-plastics-swindon/contact/enquiry-plastic-moulding-antistatic-packaging-vacuum-forming.php)
- Inpress Plastics (Wick) http://www.inpressplastics.co.uk/
- Design4Plastics (Yorkshire) http://www.design4plastics.com/

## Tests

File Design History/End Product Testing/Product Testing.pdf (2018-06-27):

# Final Product Testing

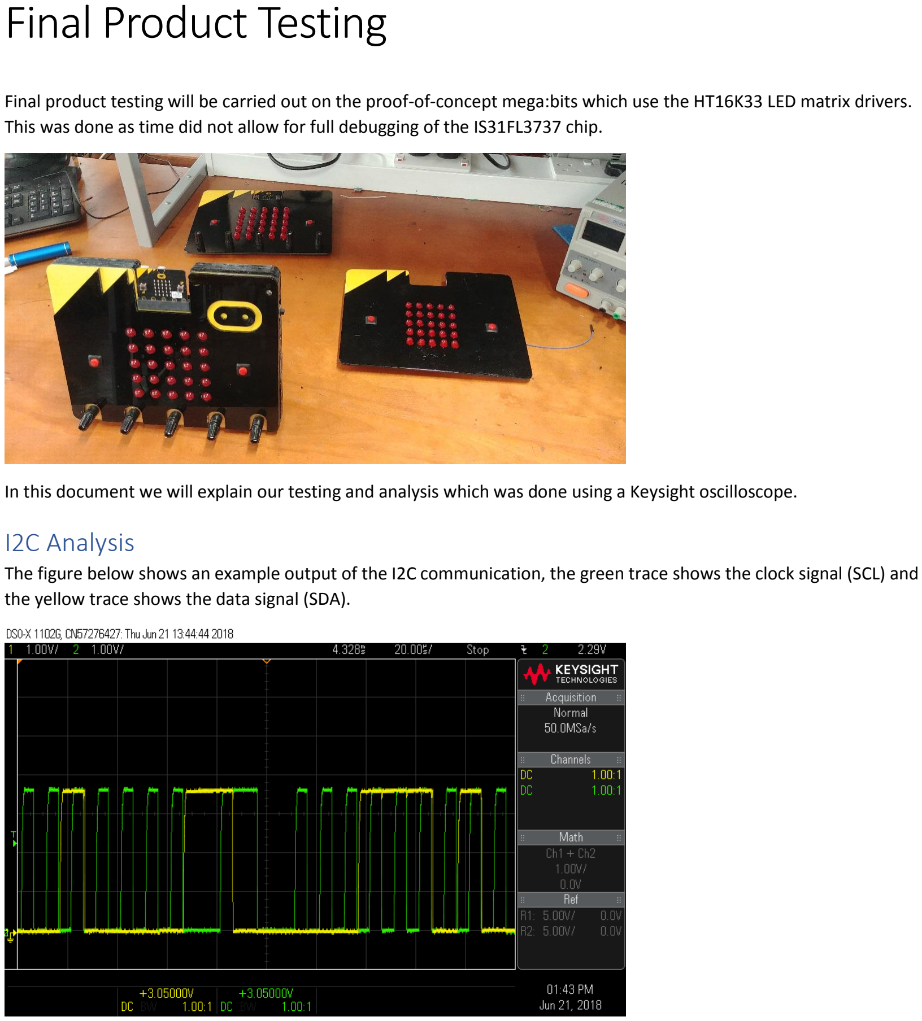
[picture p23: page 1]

Final product testing will be carried out on the proof-of-concept mega:bits which use the HT16K33 LED matrix drivers. This was done as time did not allow for full debugging of the IS31FL3737 chip.

In this document we will explain our testing and analysis which was done using a Keysight oscilloscope.

## I2C Analysis

The figure below shows an example output of the I2C communication, the green trace shows the clock signal (SCL) and the yellow trace shows the data signal (SDA).

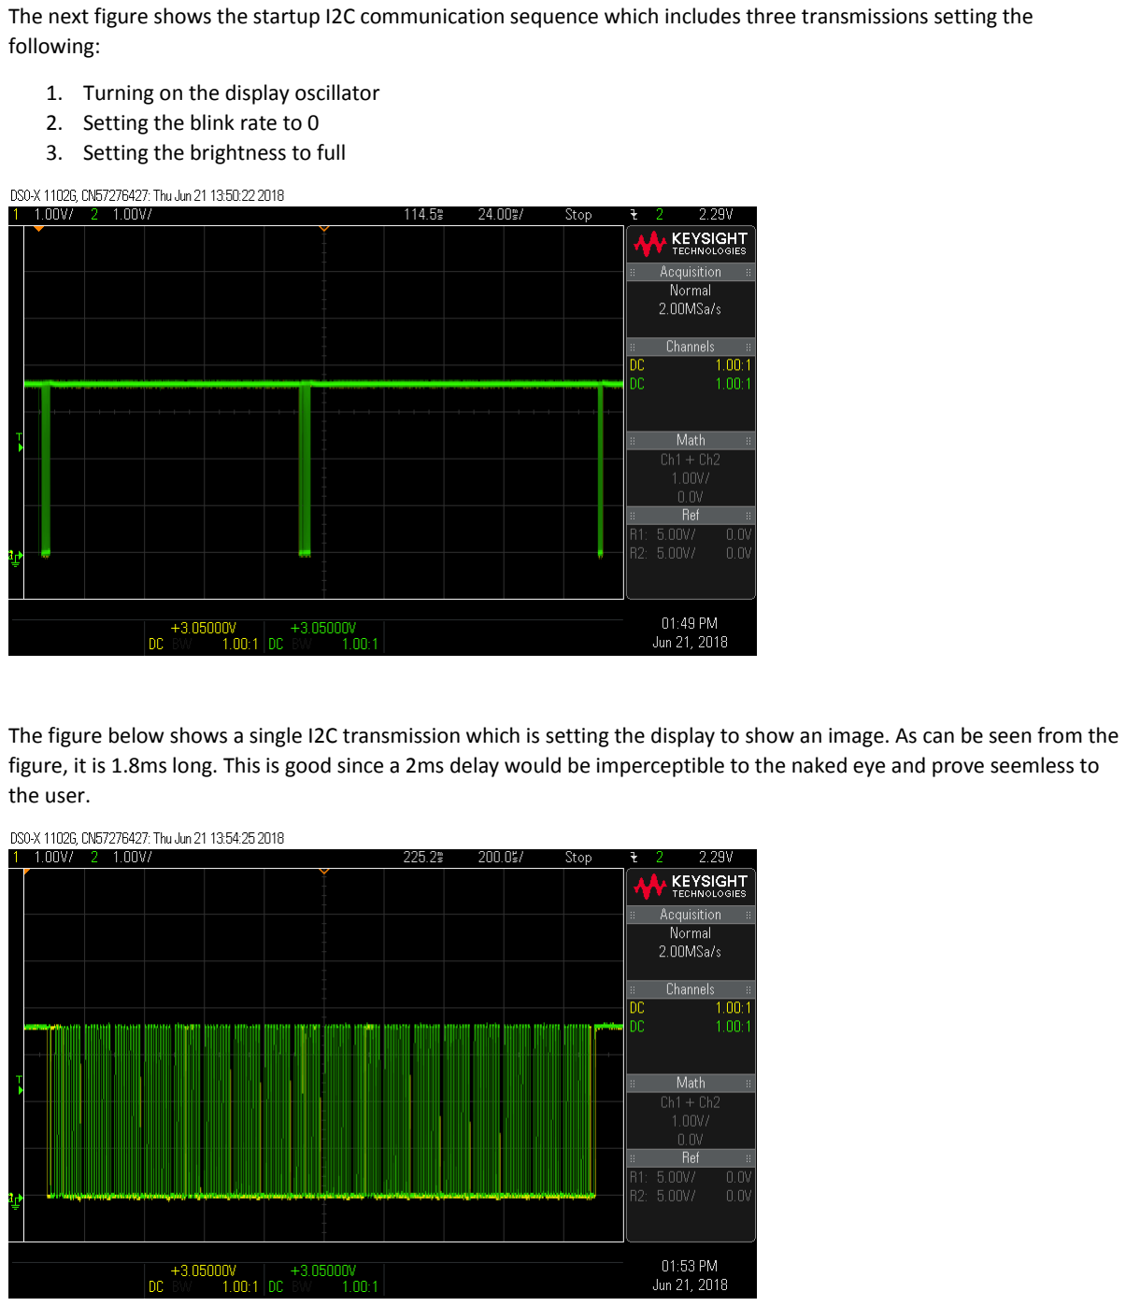
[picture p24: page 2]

The next figure shows the startup I2C communication sequence which includes three transmissions setting the following:

1. Turning on the display oscillator
2. Setting the blink rate to 0
3. Setting the brightness to full

The figure below shows a single I2C transmission which is setting the display to show an image. As can be seen from the figure, it is 1.8ms long. This is good since a 2ms delay would be imperceptible to the naked eye and prove seemless to the user.

## Handshake Analysis

The figure below shows the 1kHz handshake frequency (yellow trace) against the 3.3V bus voltage. The frequency proved to be accurate and stable which is obviously desirable for confident identification by the micro:bit.

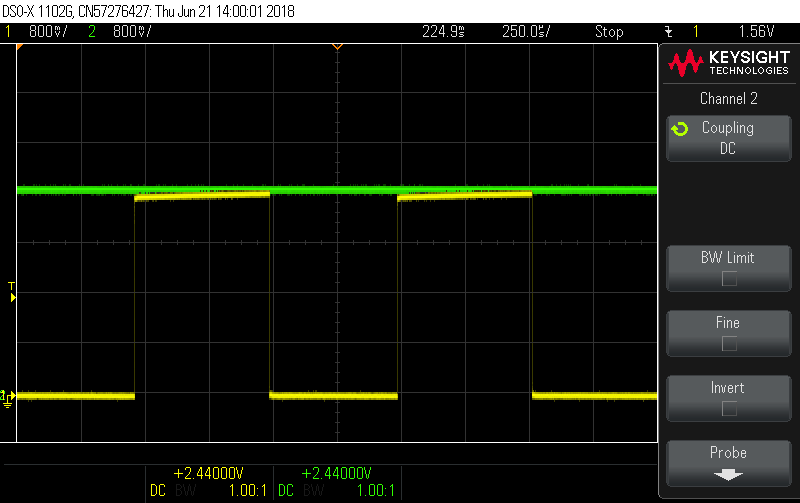
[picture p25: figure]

## Display Tests

Many example programs, images and text strings were tested, and all performed perfectly as expected. Brightness changes and animations (image/text scrolling) also worked flawlessly.

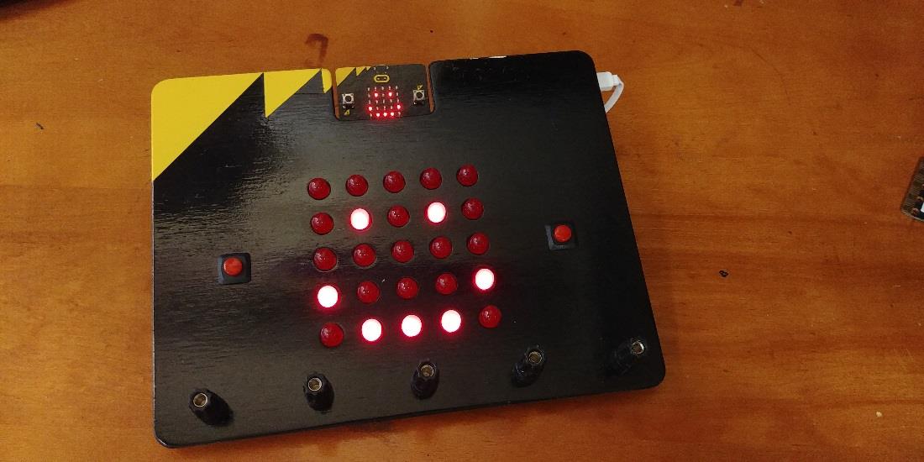
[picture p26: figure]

## Distance Tests

The mega:bit was also tested at distance, to simulate a large classroom. The figure below shows one such test, the mega:bit worked perfectly up to the full width of the labs available which is around 25 meters, much larger than most standard classrooms. The device was also tested in direct sun light outside and it reached 5m with sun shining towards the front of the teacher, and with sun behind the teacher it reached about 15m. Although this is not adequate for teaching, it is not expected to be used outside since the students need to use computers, so therefore is not an issue.

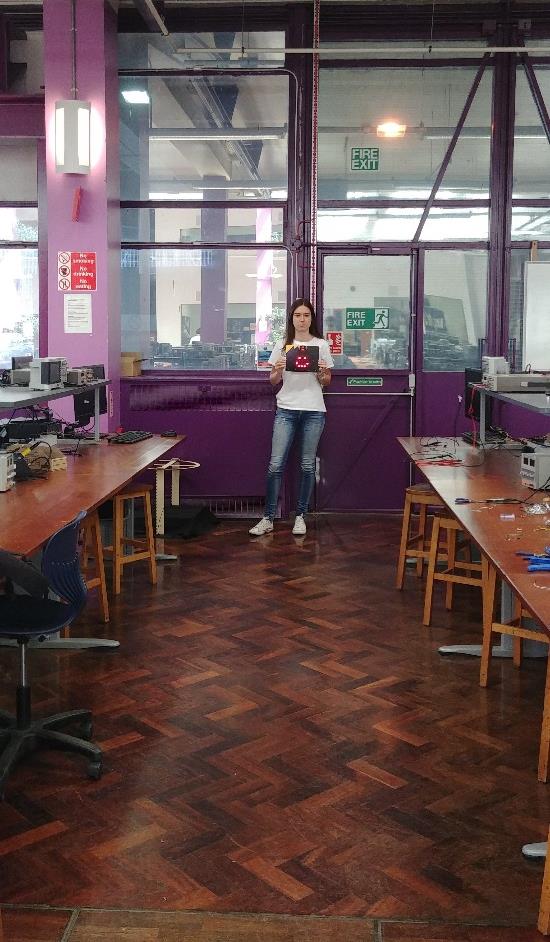
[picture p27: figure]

## Short Circuit Tests

The figure below shows the 3.3V and 5V rail voltages.

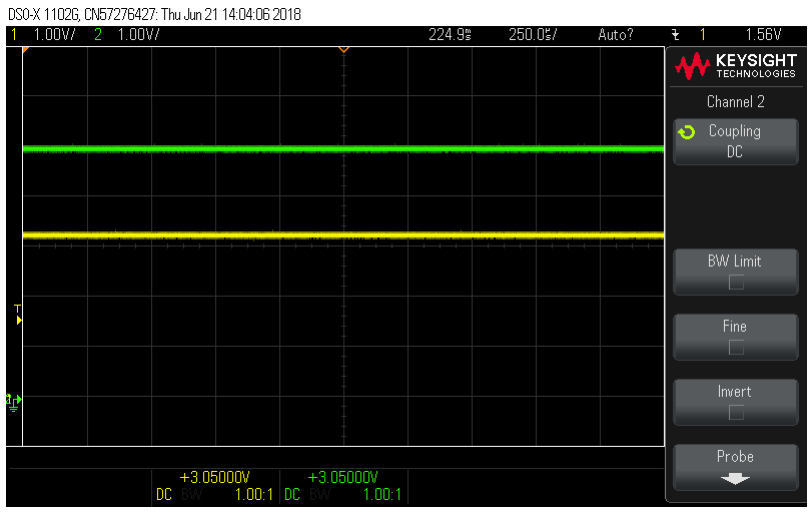
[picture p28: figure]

The final test was a quick short circuit test in which we methodically short circuited every track on the PCB for up to 3 seconds. Although this is obviously not advised since current draws would spike through the devices, it was able to withstand all tests and, at the most, just resulted in a hard reset.

## Conclusion

In conclusion the mega:bit performs its required tasks perfectly without issues.

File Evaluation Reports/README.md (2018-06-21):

This folders contains the two end of project reports that assess the social, environmental and ethical consequences related to the project and reflect on areas for improvement.

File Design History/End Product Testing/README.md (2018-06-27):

A brief document demonstrating some of the testing done on the final product design.

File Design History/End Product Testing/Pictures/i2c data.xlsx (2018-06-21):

 | x-axis | 1.00 | 2.00
 | second | Volt | Volt
0.360 | 0.00036 | 3.62 | 3.62
0.362 | 0.0003625 | 3.65 | 3.65
0.365 | 0.000365 | 3.64 | 3.65
0.367 | 0.0003675 | 3.65 | 3.67
0.370 | 0.00037 | 3.61 | 3.69
0.372 | 0.0003725 | 3.69 | 3.66
0.375 | 0.000375 | 3.63 | 3.63
0.378 | 0.0003775 | 3.65 | 3.68
0.380 | 0.00038 | 3.62 | 3.65
0.382 | 0.0003825 | 3.65 | 3.69
0.385 | 0.000385 | 3.63 | 3.69
0.388 | 0.0003875 | 3.63 | 3.67
0.390 | 0.00039 | 3.65 | 3.65
0.393 | 0.0003925 | 3.65 | 3.65
0.395 | 0.000395 | 3.65 | 3.67
0.398 | 0.0003975 | 3.64 | 3.65
0.400 | 0.0004 | 3.65 | 3.65
0.403 | 0.0004025 | 3.65 | 3.65
0.405 | 0.000405 | 3.63 | 3.65
0.407 | 0.0004075 | 3.65 | 3.65
0.410 | 0.00041 | 3.69 | 3.65
0.412 | 0.0004125 | 3.61 | 3.65
0.415 | 0.000415 | 3.65 | 3.68
0.418 | 0.0004175 | 3.65 | 3.69
0.420 | 0.00042 | 3.65 | 3.69
0.423 | 0.0004225 | 3.66 | 3.62
0.425 | 0.000425 | 3.64 | 3.68
0.427 | 0.0004275 | 3.65 | 3.69
0.430 | 0.00043 | 3.63 | 3.66
0.432 | 0.0004325 | 3.62 | 3.66
0.435 | 0.000435 | 3.65 | 3.65
0.438 | 0.0004375 | 3.64 | 3.67
0.440 | 0.00044 | 3.65 | 3.65
0.443 | 0.0004425 | 3.62 | 3.66
0.445 | 0.000445 | 3.65 | 3.65
0.448 | 0.0004475 | 3.65 | 3.69
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

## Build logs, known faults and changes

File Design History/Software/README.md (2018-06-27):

Item | Description
--- | --- 
/code | Includes files from the DAL which are edited 
/modified-DAL | Complete DAL (not up-to-date) 
Software Design Process.pdf | Description of the software development process 
i2c-addresses.pdf | List of I2C addresses used by Adafruit devices (referenced in file above)

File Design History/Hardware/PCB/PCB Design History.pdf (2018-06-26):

# Design aspects

### Power

The Micro:bit requires 3.3V to be powered via the edge connector, however, the HT16K33 LED driver requires 4.5-5.5V in order to work correctly.
A few ideas were considered to have a battery powered option as well as USB to power the circuit. We had initially begun designing based on 4xAA batteries (6V) being stepped down to 5V through a linear voltage regulator. However, it was soon made clear that there are multiple problems with this design:
- Linear voltage regulators generally require ~2V above the desired output voltage to work correctly.
- If the batteries discharge below 5V, the output will always be below 5V.

A Buck converter was then considered, but this also suffered from the problem whereby if the 4xAA voltage discharges below 5V, the output cannot match the desired 5V as a buck converter can only step down.
We then decided to go with a 2xAA 3V configuration using a boost converter to step up the voltage to 5V.
A boost topology converter was used to step up the ~3V from the 2xAA batteries to 5V in a closed loop configuration. This allows for the largest range of discharge in the batteries as the boost converter can function until the 2xAA drops to round 1.4V.

With USB power, the 5V can directly go to power the LED driver whilst being fed through a 3.3V linear voltage regulator to power the Micro:bit and edge connector.

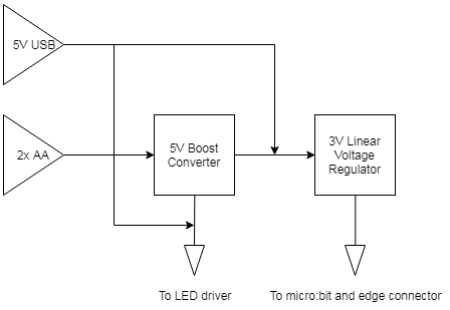
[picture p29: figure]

A consideration that needs to be investigated is the amount of current being drawn from the batteries in order to allow this step-up to occur at low battery voltages. It could lead to a runaway situation in battery discharging and overheating.

Another idea was to have a switch to choose between power supplies. This avoids the potential danger of having both the USB and batteries connected at the same time.

This has been implemented via a DPDT on-off-on switch. When in position one, the USB is connected directly to the 5V rail of the circuit. When in the middle position, the mega bit is off. When in position 3, the batteries are connected to the input of the Boost converter.

### PCB Revision 1

The revision 1 PCB is a small version of the Megabit used to test our design. It will have the core functionality of the desired end product purely to ensure that we have a working foundation to build upon in future revisions, which will have more features and be more complex.

The main design decisions and rational are shown below:

Decision: 5v USB power ONLY through an external breakout board

Rational: Battery powered operation requires lots of external circuitry in order to work. The USB header also uses extremely small and awkward to solder surface mount pins. We therefore decided to omit the battery powered portion of the circuit and opt for a USB breakout board package to minimise the amount of time wasted on soldering. It is currently expected that the battery supply will be included on the 2nd revision, however this is subject to change following market research.

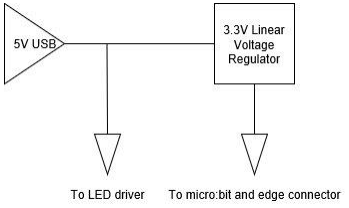
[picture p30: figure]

Decision: 28-pin LED driver chip used instead of 24-pin that was used in the proof of concept.

Rational: When coming to order the LED chip, it was discovered that the 24-pin version of the chip was not easily orderable through Imperials trusted suppliers. We therefore were forced to use the 28-pin version, which will mean that some software changes will be necessary.

Decision: L-793SRD 8 mm round super bright red LED

Rational: The LEDs were chosen to be bright and large so that these are visible over large distances.

Decision: Layout of the PCB compressed to 62 x 57 mm.

Rational: As this is a testing board and manufacturing single PCBs have a high cost, we tried to keep the PCB as small as possible while having the most functional and visually appealing display. Hence, the header is at the top where the micro: bit would be connected, followed by the LED driver and pull-up resistors; the micro USB port is located on the side for an easier access and below the LED matrix with the two buttons on the side.

Conclusion:

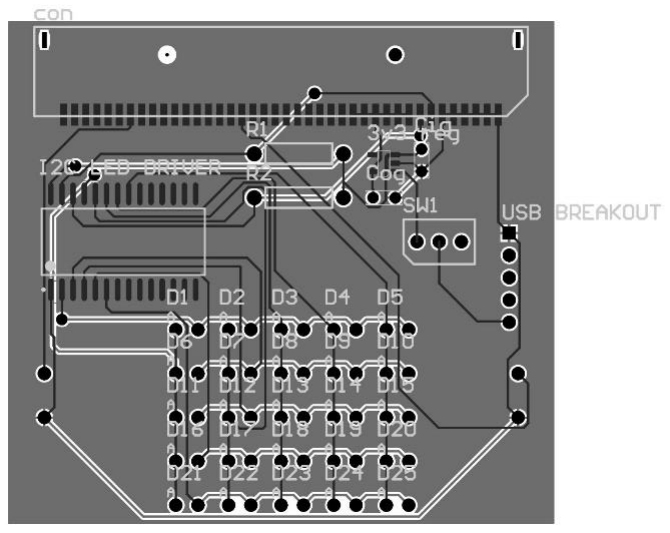
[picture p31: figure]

The first revision PCB worked well, despite the spacing for the LEDs being too small and having to make an external stripboard LED matrix. The next steps were now to think about additional powering methods.
The LED stripboard matrix was tested across the whole length of the Level 1 labs (30-50 meters) and was well visible at all distances. We are therefore pleased with the brightness and visibility performance of the LEDs.

### PCB Revision 2

After the success of the first PCB and discussing with our client, we decided to build a second revision with an added power option to test, namely a 9V and 2xAA battery power.

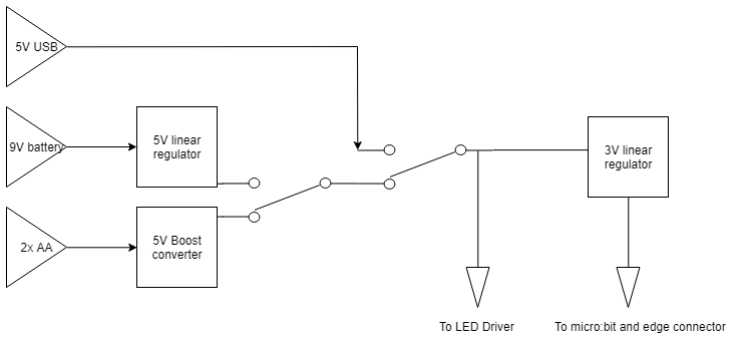
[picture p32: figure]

The purpose of this was mainly to test the different battery powered solutions that we had in mind. Each way of providing 5V is isolated with a switch and so can be disabled if it doesn’t work as intended.

We decided to use proper switches and the correct spacing for LEDs in this revision, as well as adding in test points to measure the SCL, SDA and +5, +3.3 points.

Pads for the large edge connectors were also added.

We chose to place all the components on the rear of the PCB and the interface controls and LEDS on the front to mimic what we would like the megabit to be in the end. The ground plane was removed to help with soldering but may well be re-introduced in the final revision.

Conclusion:

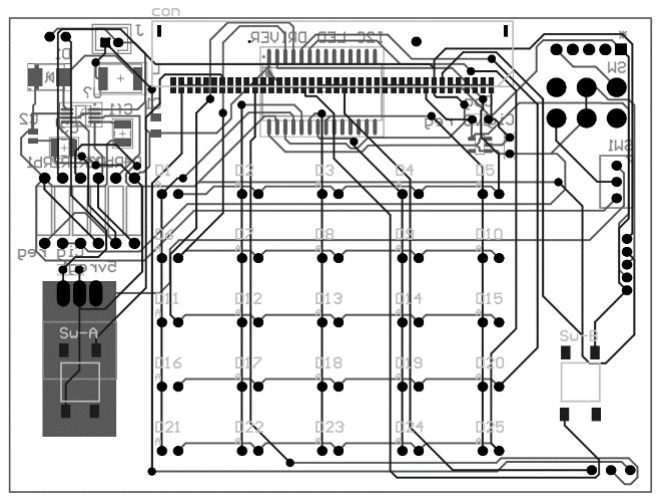
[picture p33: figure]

We found that the 9V battery power worked well and is a feasible way to power the circuit, however we are concerned about power consumption. Something noticed was that when the megabit was not plugged in, the battery and 5v regulator were warm, likely to be due to the linear regulator being designed to run at a higher input voltage.
It was decided that in the final PCB we shall use a USB and 9V supply, assuming there is not a better battery supply available. The boost circuit was unable to be tested due to inconsistencies in the PCB footprints and what was received, however we decided that it is not worth pursuing anyway.

### PCB Revision 3

The revision 3 board was primarily made to test a different method of LED driving that allows for individual LED brightness control. Two 16-channel LED driver chips (32 total to have a 25-LED matrix) are used on the same I2C bus. An added benefit is that these chips are able to run off 3.3V, removing the need for any 5v regulation.

The board is also to be used in testing a Buck DC-DC converter which, if works, will remove the need for a linear 3.3V regulator and increase efficiency in the circuit greatly, which is important for battery powered operations.

A diagram of the revision is shown below:

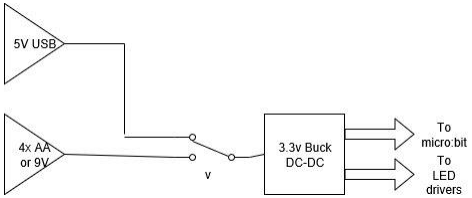
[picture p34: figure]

It is expected that the final Megabit will be using the 5v HT16K33 chip rather than a different type of chip which is able to run off 3.3V. In this case, the 4xAA will be omitted and only a 9V battery can be used. This is so that a 5V linear regulator can be used which requires Vin > 6V.

Conclusion:
Due to delivery issues outside of our control, we did not have the time to test this circuit. In addition to this, in a meeting with Jonny, he did not like the 2 chip design (despite the final design using only a single chip), and told us to stick with the original.

### Main PCB

The main PCB will have the core functionality plus any extra features that we feel add value to the product whilst retaining its simple interface and teaching value.

A major change in the PCB was the use of a new chip, the IS31FL3737 chip which comes in a compact 40 pin QFN package. The benefits of this chip are that it allows for individual LED brightness and runs off 3v, allowing the power circuitry to be greatly simplified as a 5V rail is no longer needed and a 3.3V buck converter can be used with a wide range of input voltages allowing for an elegant power solution.

Datasheets for the IS chip and Buck converter can be found in the components section.

Handshake
In order for the micro:bit to sense whether it is plugged into the mega:bit, we devised a simple handshake in order for the megabit to ‘communicate’ with the microbit to tell it that it is connected.

The way that this works is with a simple and cheap to manufacture 555 square wave oscillator which sends a 1kHz square wave to the accessibility pin of the micro:bit.

When the micro:bit is powered on, it looks to see if the handshake is present. If it is, it then looks to see which I2C address is being used and uses this address to send the LED matrix data.

If the handshake is not present, then any addresses used on the I2C bus are assumed to be normal peripherals and not the mega:bit.

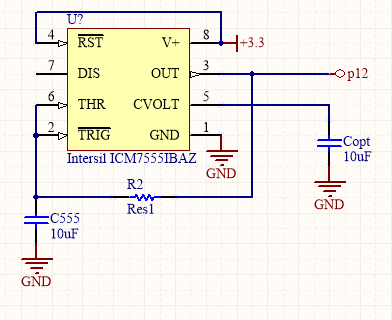
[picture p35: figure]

Where p12 is the accessibility pin.

Battery indicator

To indicate the voltage status of the 9 V battery source, it would be helpful to know when it presents low voltage as the linear regulator requires at least 7 V of input voltage to properly work. Hence, we have added two extra indicators:

A) Power On indicator: a simple 3 mm green LED that connects to the voltage source.
B) Low battery indicator: R1 and R2 form a potential divider that would set the voltage threshold of the following BJT. R3 works as an electrical insulator for the current. In this case, when the source voltage is less than 7.2 V, the red LED would turn on to suggest a change of battery and be off when it's located above that threshold.

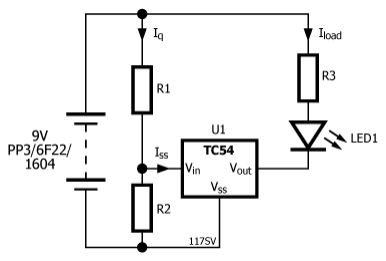
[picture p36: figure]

The datasheet can be found in the components section.

Unfortunately due to time constraints with late PCB delivery, we were unable to make the new ISSI LED driver chip work which is expected to be a software issue rather than hardware.

This PCB also had lots of extra routing for the added redundancy, which was in fact not necessary in the end, and so a revision 2 of the final megabit could be much simpler with larger tracks to reduce the difficulty with soldering and room for error.

Conclusion:
The handshake circuitry works well and only has a negligible impact on the startup of the micro:bit. The main issue with the circuitry however was that it is easy for the frequency to be changed by adding capacitance unintentionally such as by just holding the pcb. A possible fix for this is to buy a dedicated frequency generating chip which are more robust as opposed to just a general purpose 555.

A final revision has been started which removes all the unnecessary components, however the 555 chip should be changed to a more suitable unit and everything else should be made surface mount to make mass production easier.

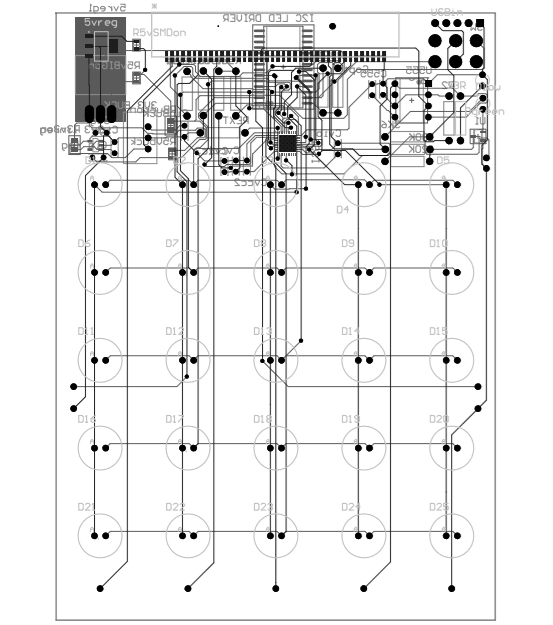
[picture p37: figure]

# Appendix

### Revision 1 Schematic and PCB

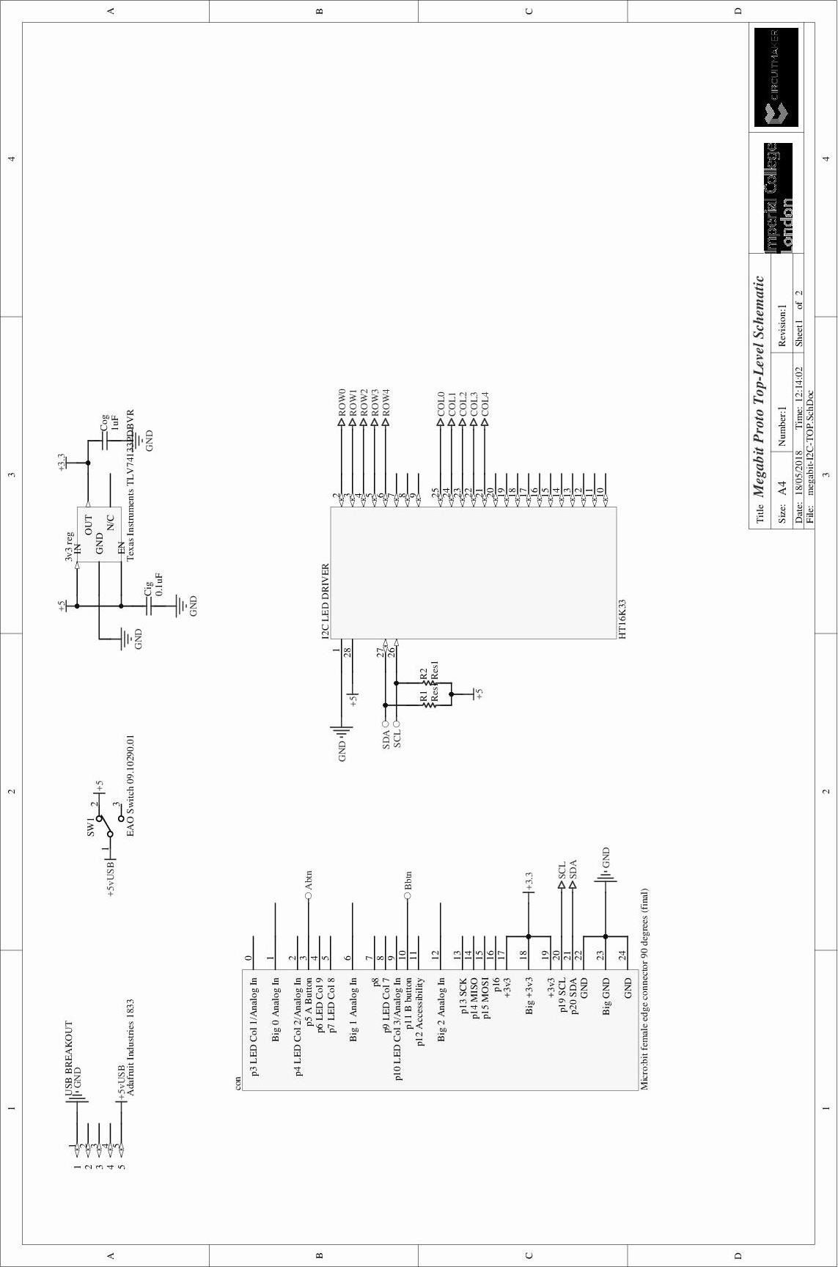
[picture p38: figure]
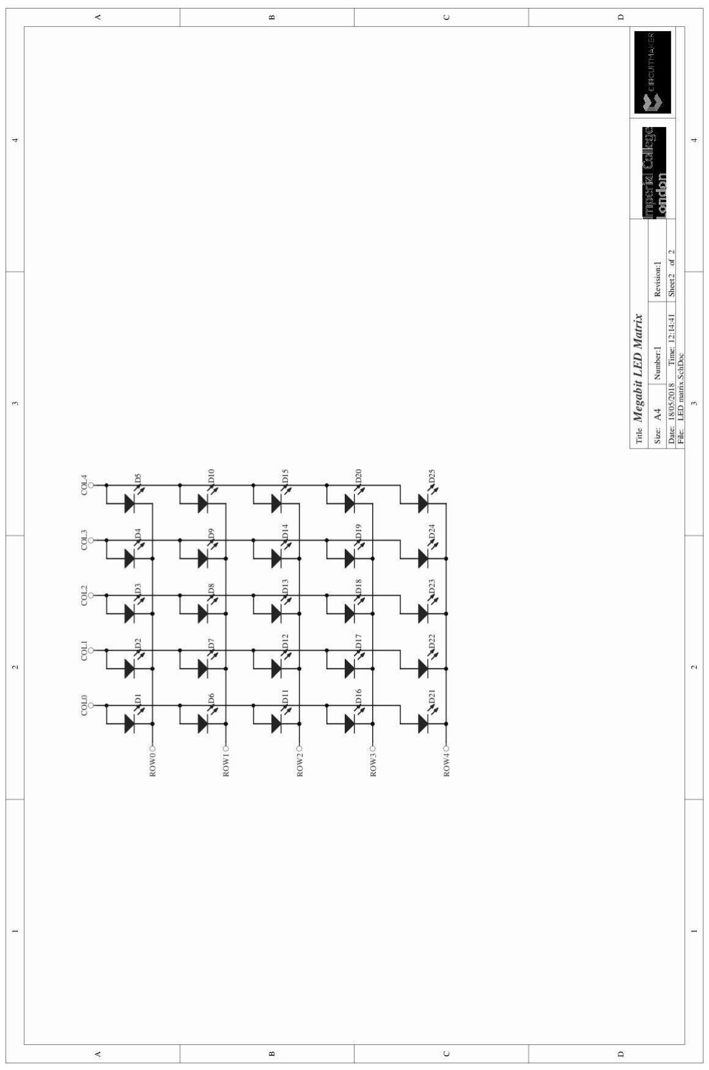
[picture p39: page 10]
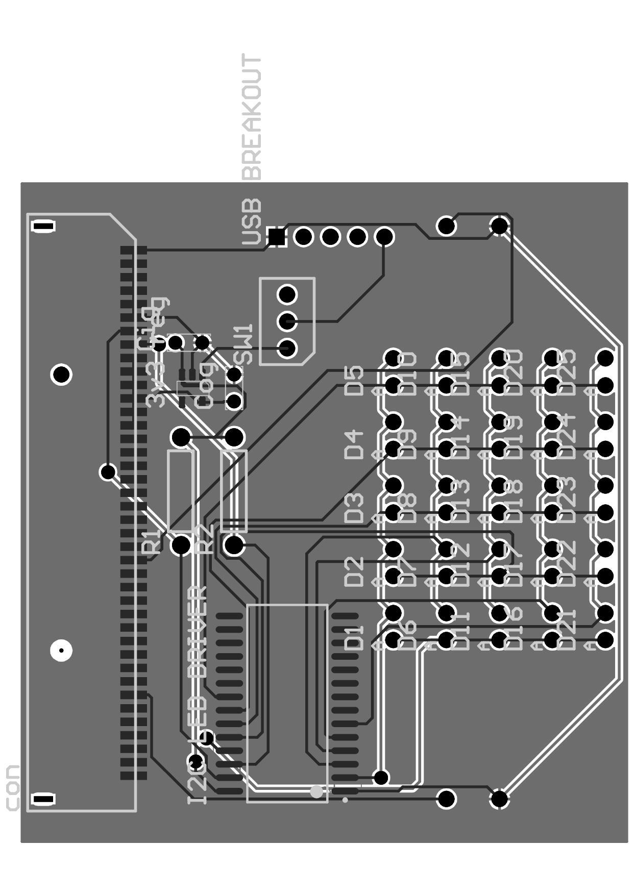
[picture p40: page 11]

### Revision 2 Schematic and PCB

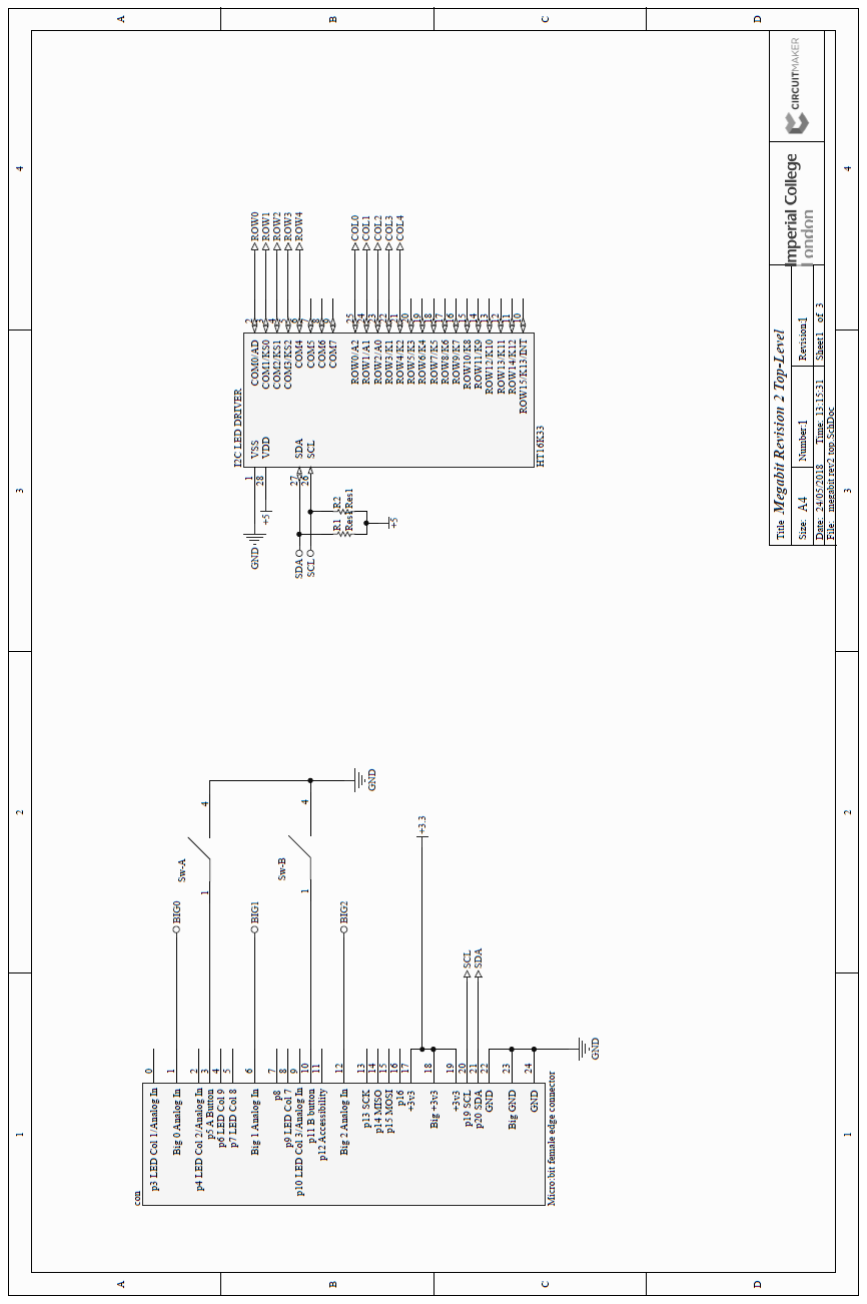
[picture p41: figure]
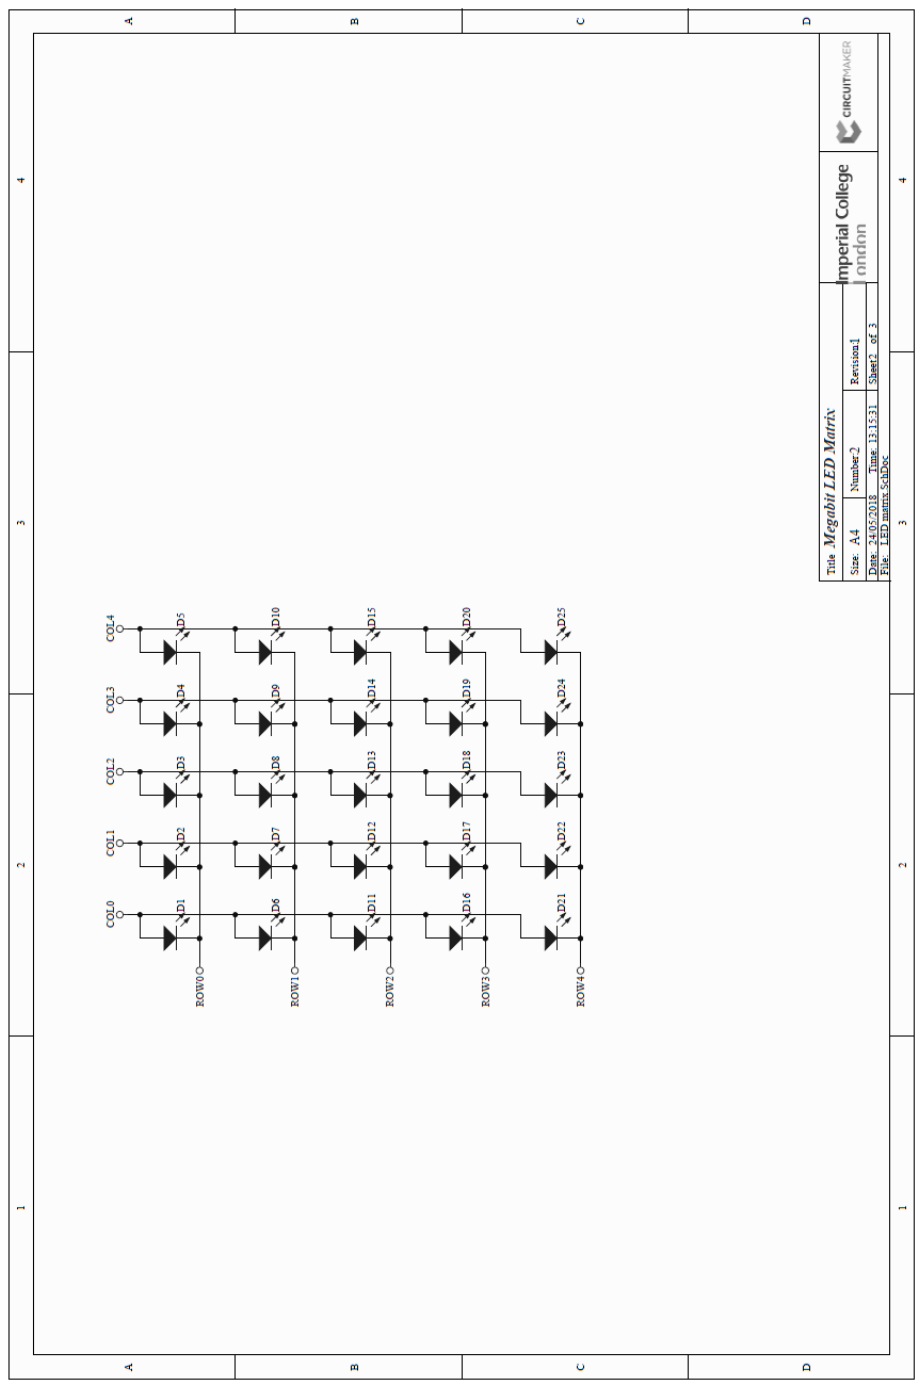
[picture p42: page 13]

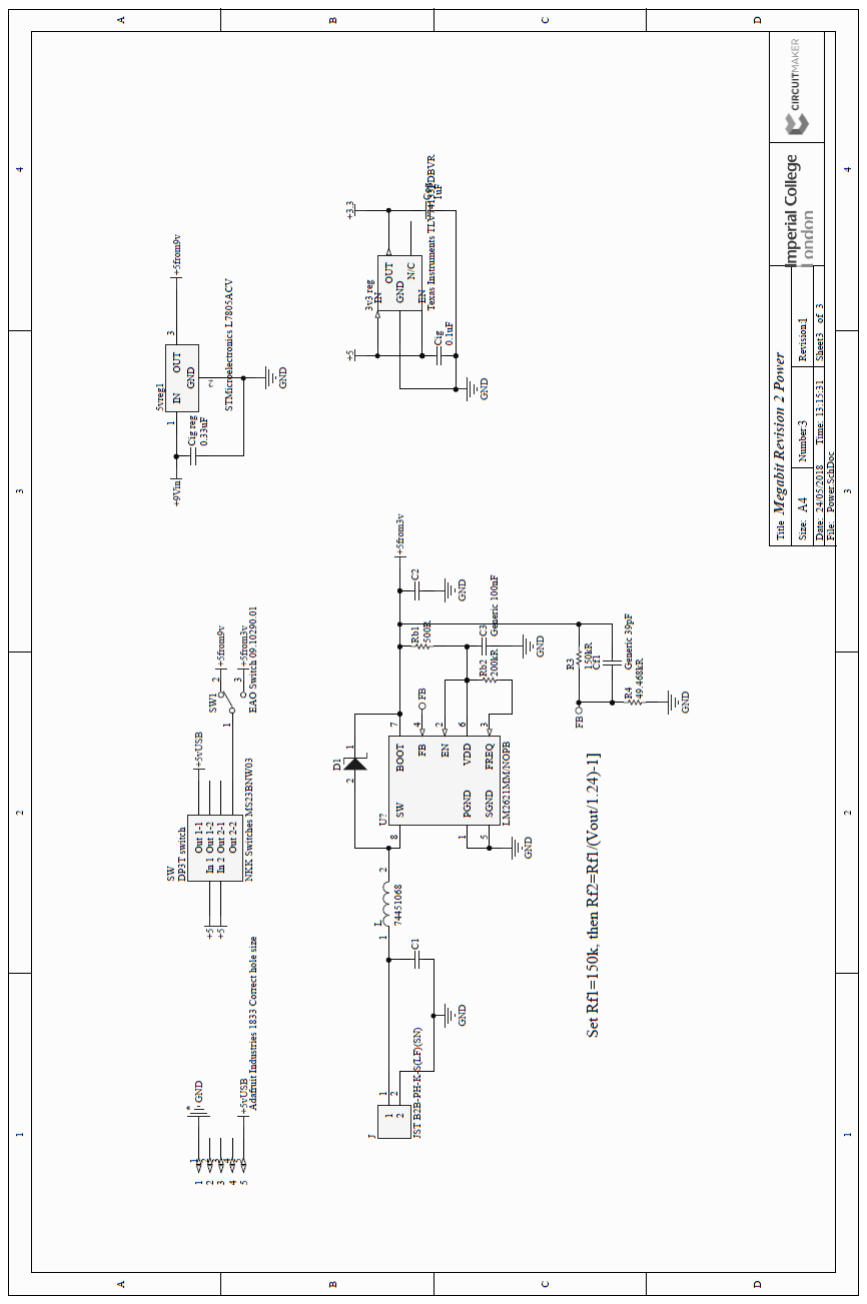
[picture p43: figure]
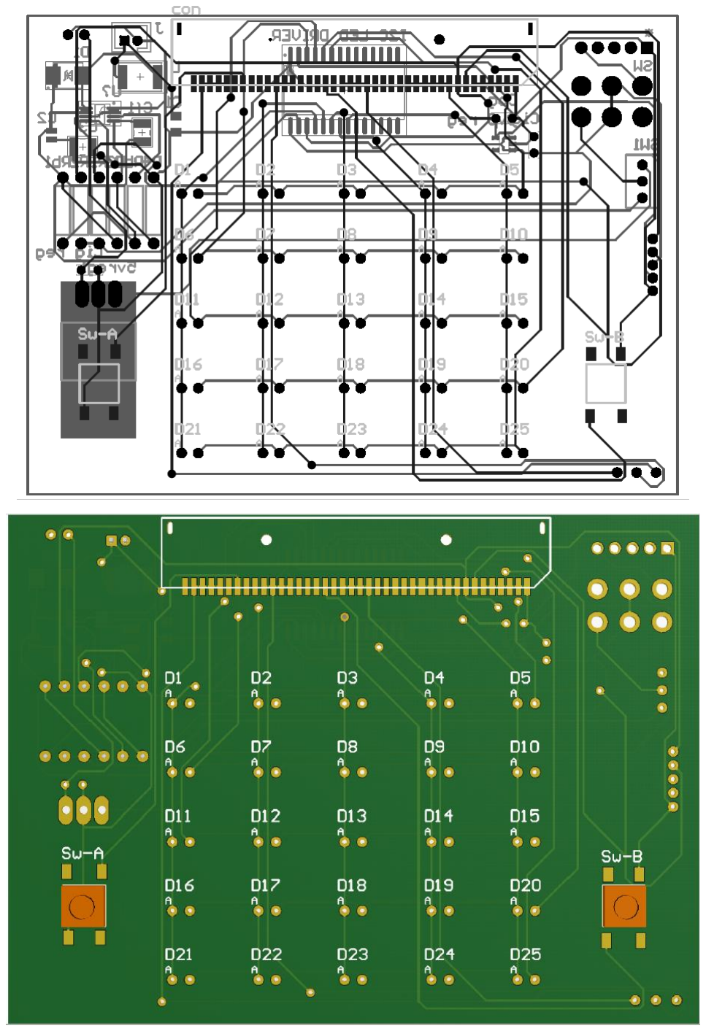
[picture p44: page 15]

### Revision 3 PCB and schematic

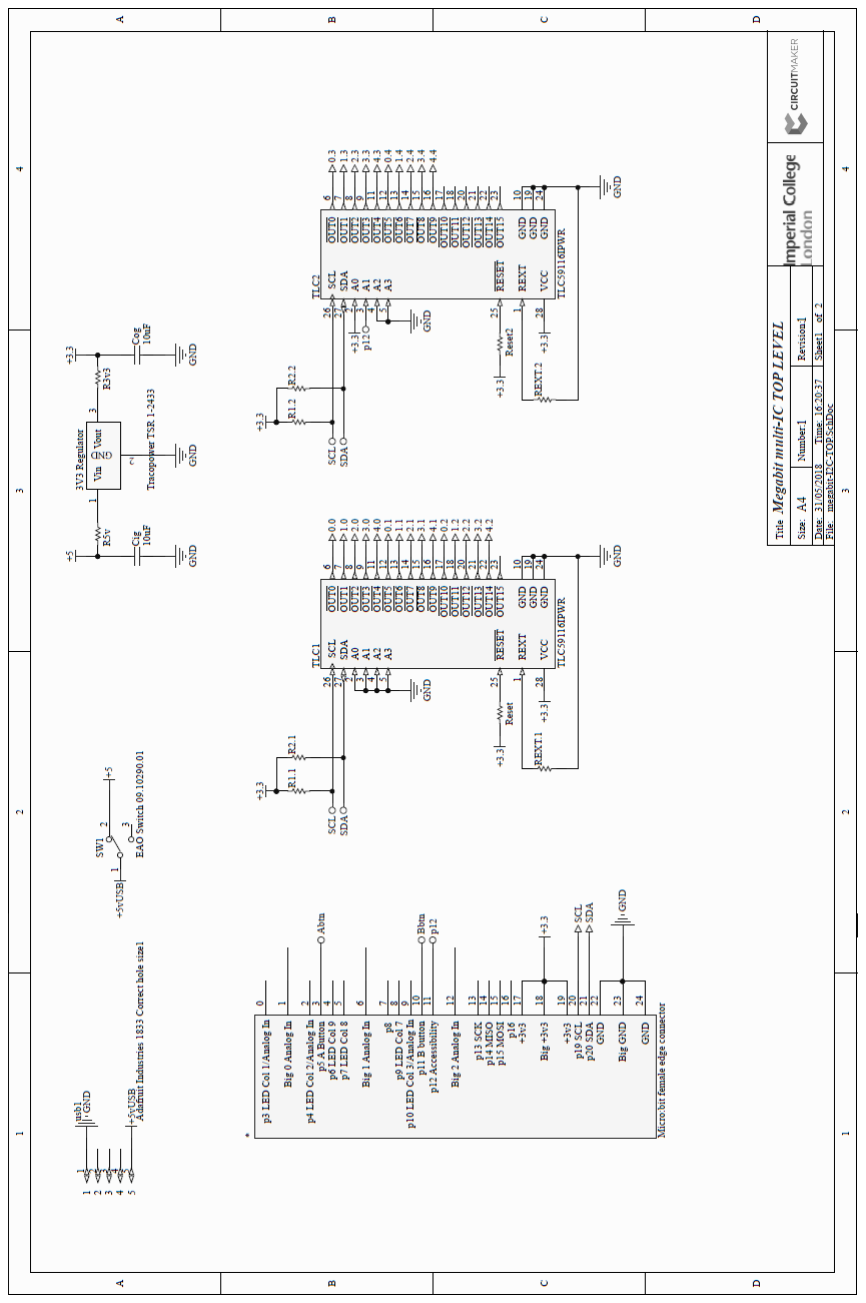
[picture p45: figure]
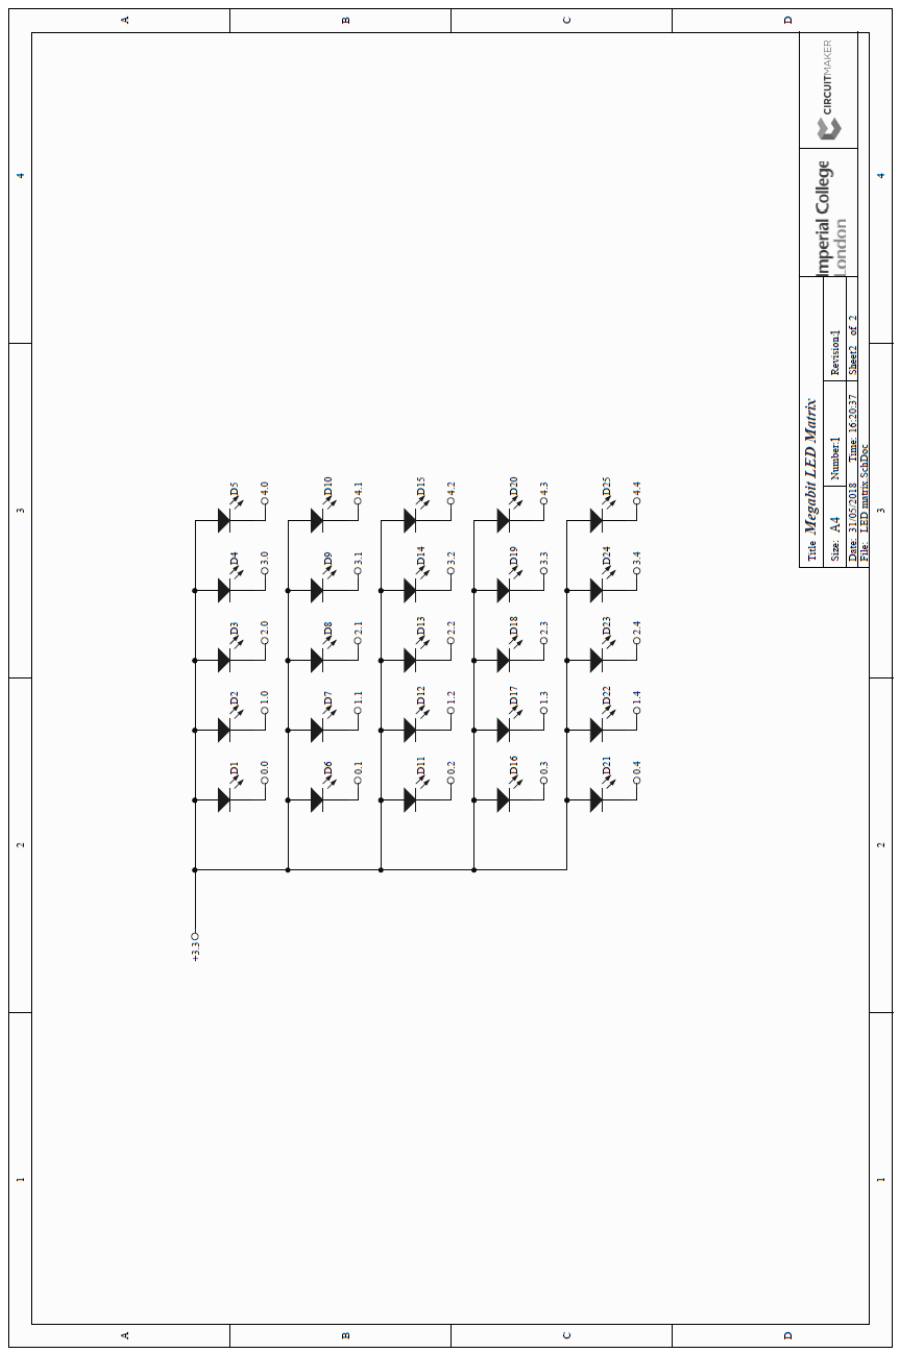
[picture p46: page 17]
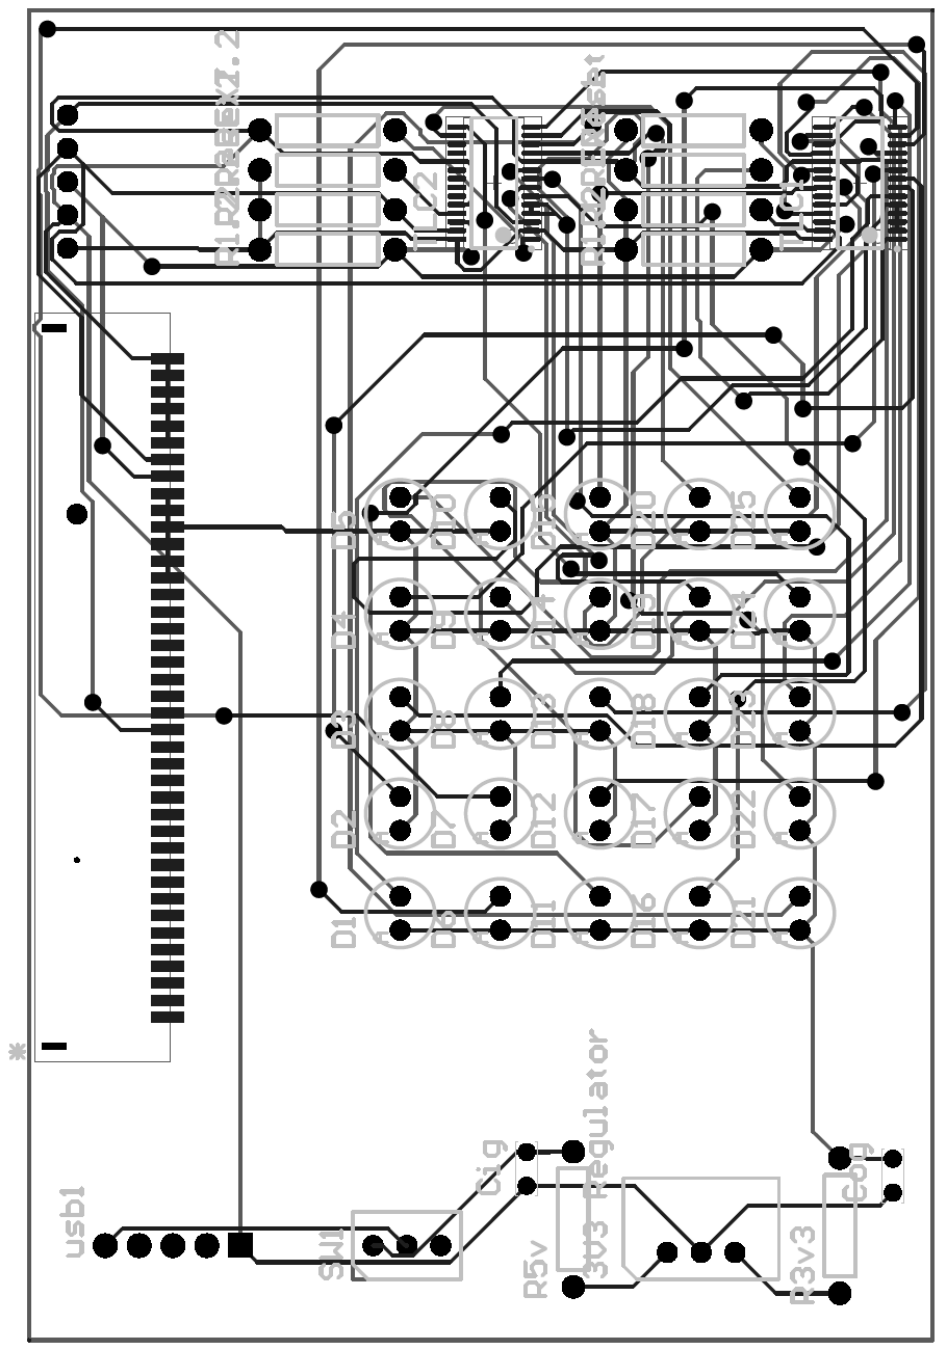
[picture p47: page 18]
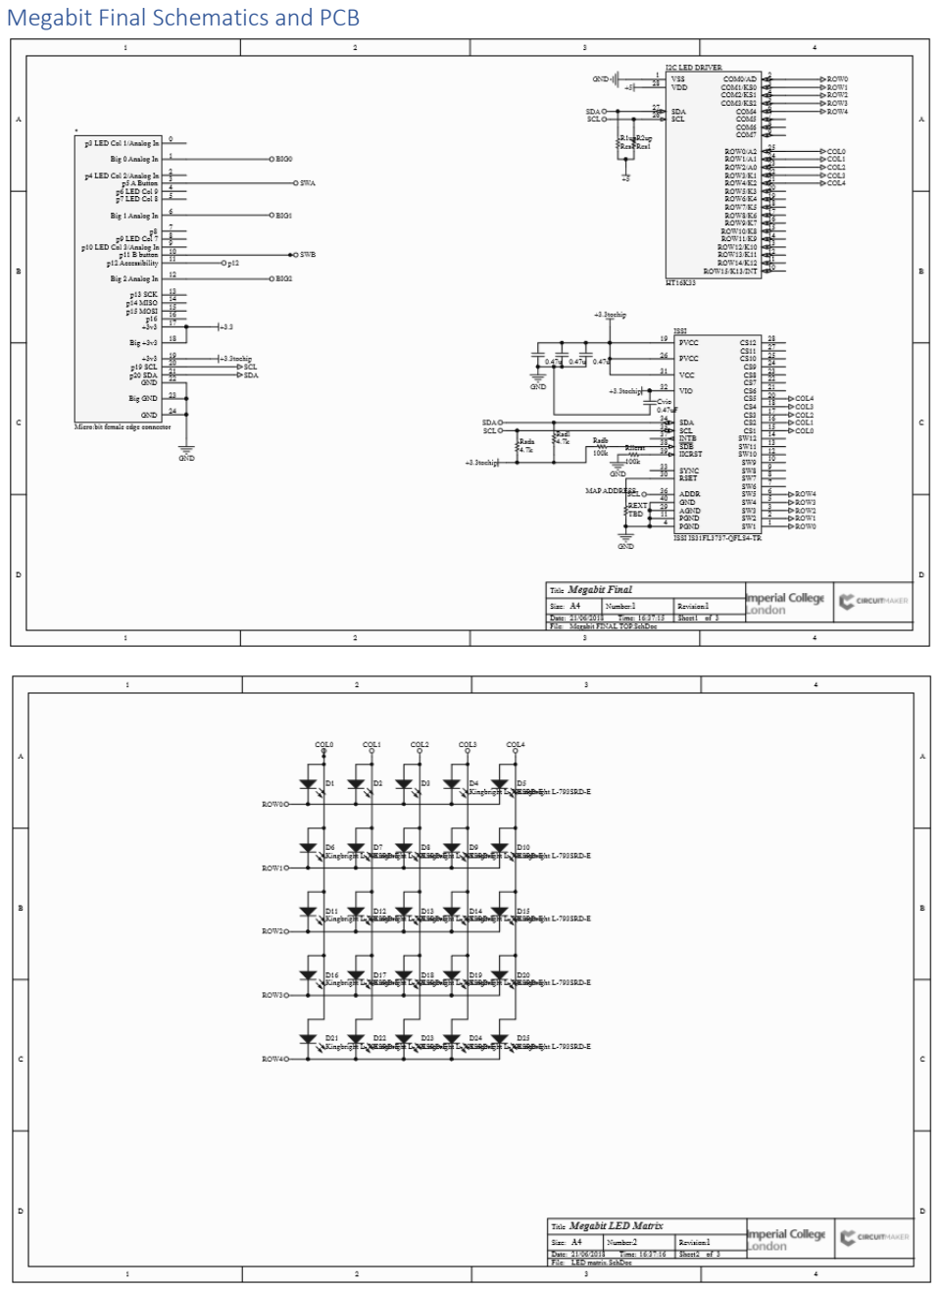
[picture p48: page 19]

### Megabit Final Schematics and PCB

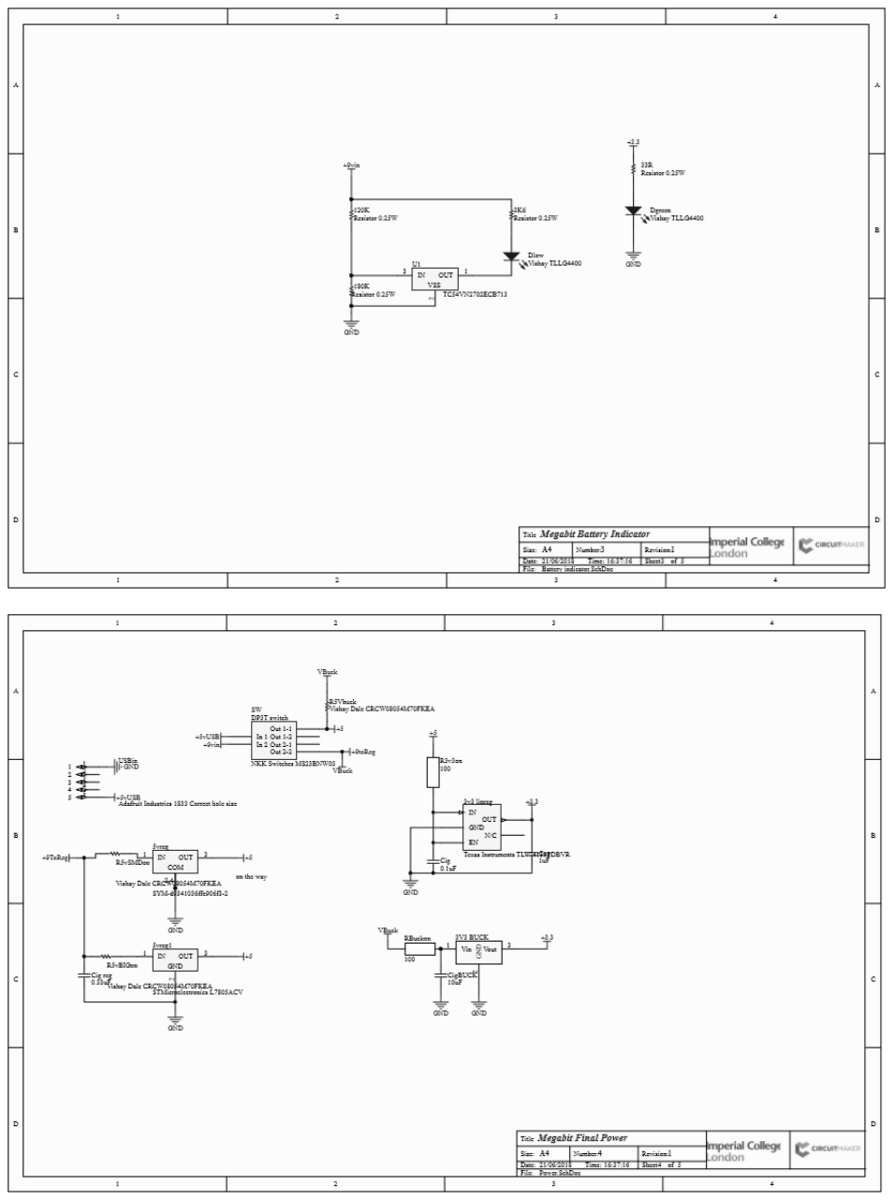
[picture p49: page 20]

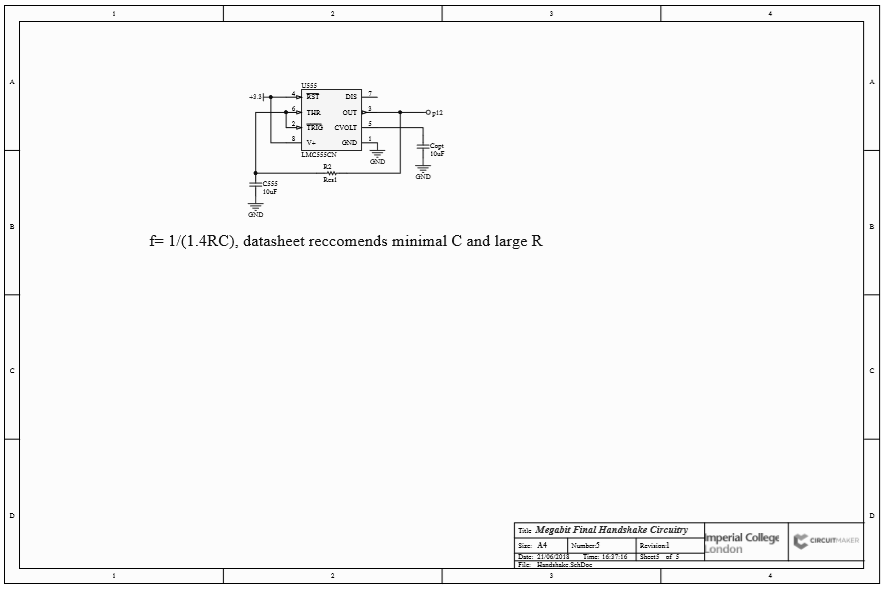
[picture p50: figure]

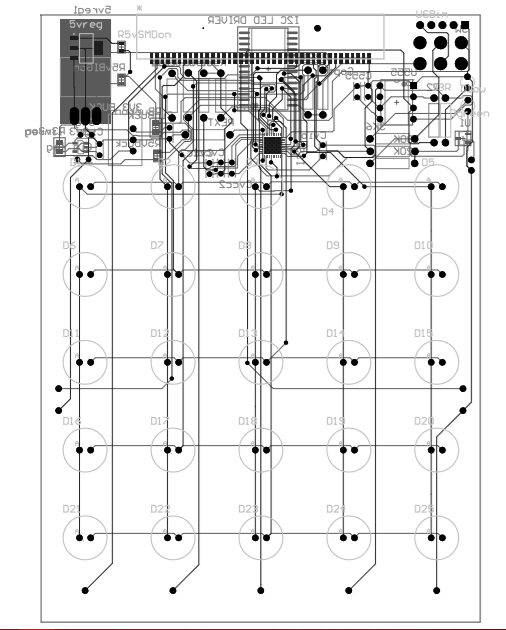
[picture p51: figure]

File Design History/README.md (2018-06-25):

This folder contains a complete design history of the project. Including software, hardware, component data and manufacturing details. It also contains documentation of testing the final design.

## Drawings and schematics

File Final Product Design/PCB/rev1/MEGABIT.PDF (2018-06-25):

# Board S

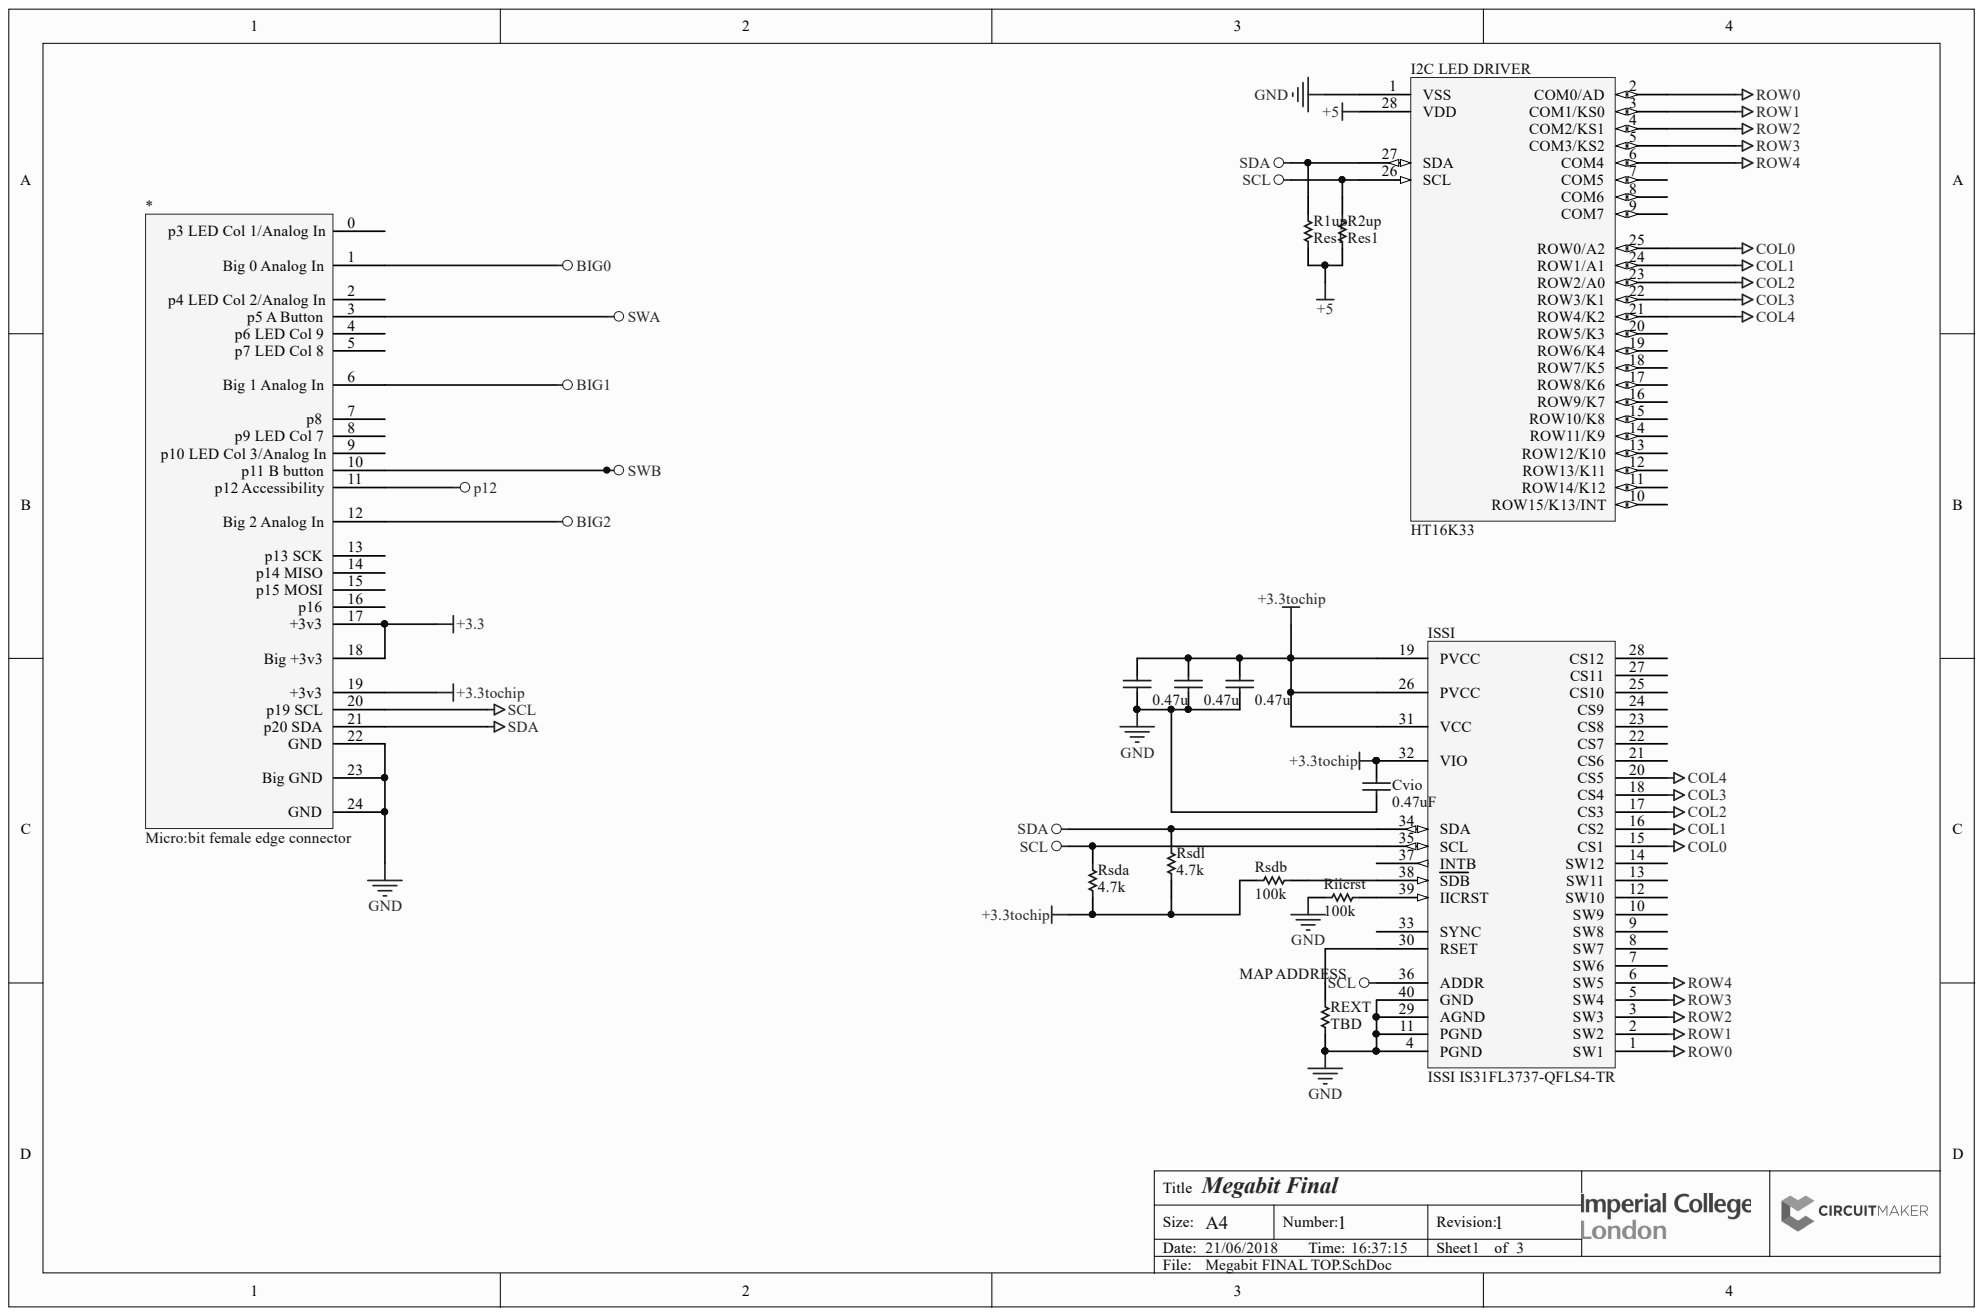
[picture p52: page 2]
t FIN; 0 ROW14/K12; 11 ROW13/K11; 12 ROW12/K10; 13 ROW11/K9; 14 ROW10/K8; 15 ROW9/K7; 16 ROW8/K6; 17 ROW7/K5; 18 ROW6/K4; 19 ROW5/K3; 20 ROW4/K2; 21 ROW3/K1; 22 ROW2/A0; 23 ROW1/A1; 24 ROW0/A2; D DRIV; 1 PGND; ISSI IS3; 3 SCK 4 MISO 5 MOSI; 9 SCL 0 SD; t female ed; PICvcc102 COCvcc1; PICvcc202 COCvcc2; PICvcc302 COCvcc3; PII2C LED DRIVER01; PII2C LED DRIVER02; PII2C LED DRIVER03; PII2C LED DRIVER04; PII2C LED DRIVER05; PII2C LED DRIVER06 PII2C LED DRIVER07; PII2C LED DRIVER08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

2 6 PIISSI026

T i t l e Mega bit Fina l

Size: A4 | N umber: 1 | Rev i s i o n : 1
Date: / / T ime: : : | | Sheet o f

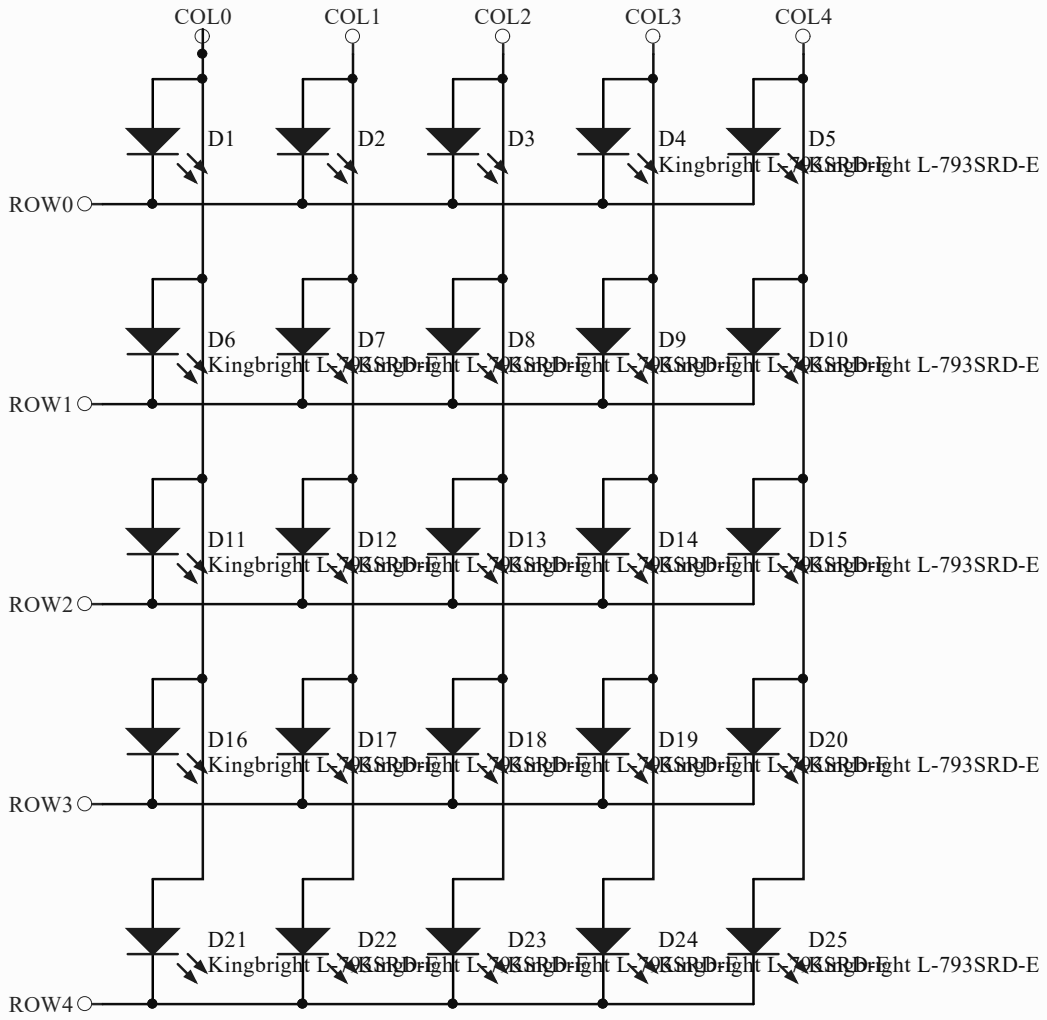
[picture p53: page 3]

Title Megabit LED Matrix

Size: A4 | Number: 2 | Revision: 1
21/06/2018 Time: 16:37:16 | | Sheet of

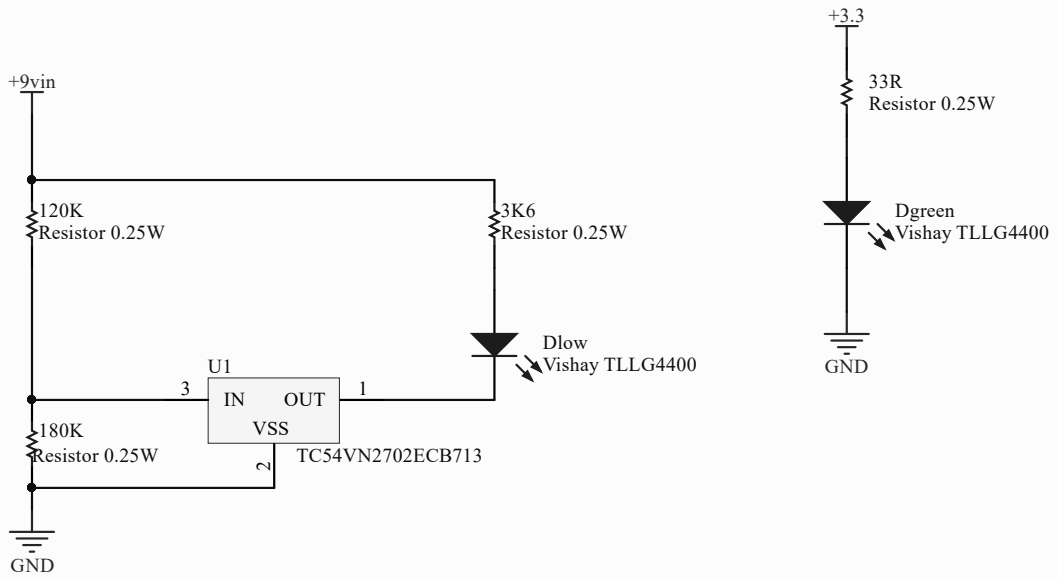
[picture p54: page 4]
tery i; PIU103; PIDlow02 PIU101

T i t l e Mega bit Battery Indicato r

Size: A4 | N umber: 3 | Rev i s i o n : 1

/ / T ime: : : | | Sheet o f

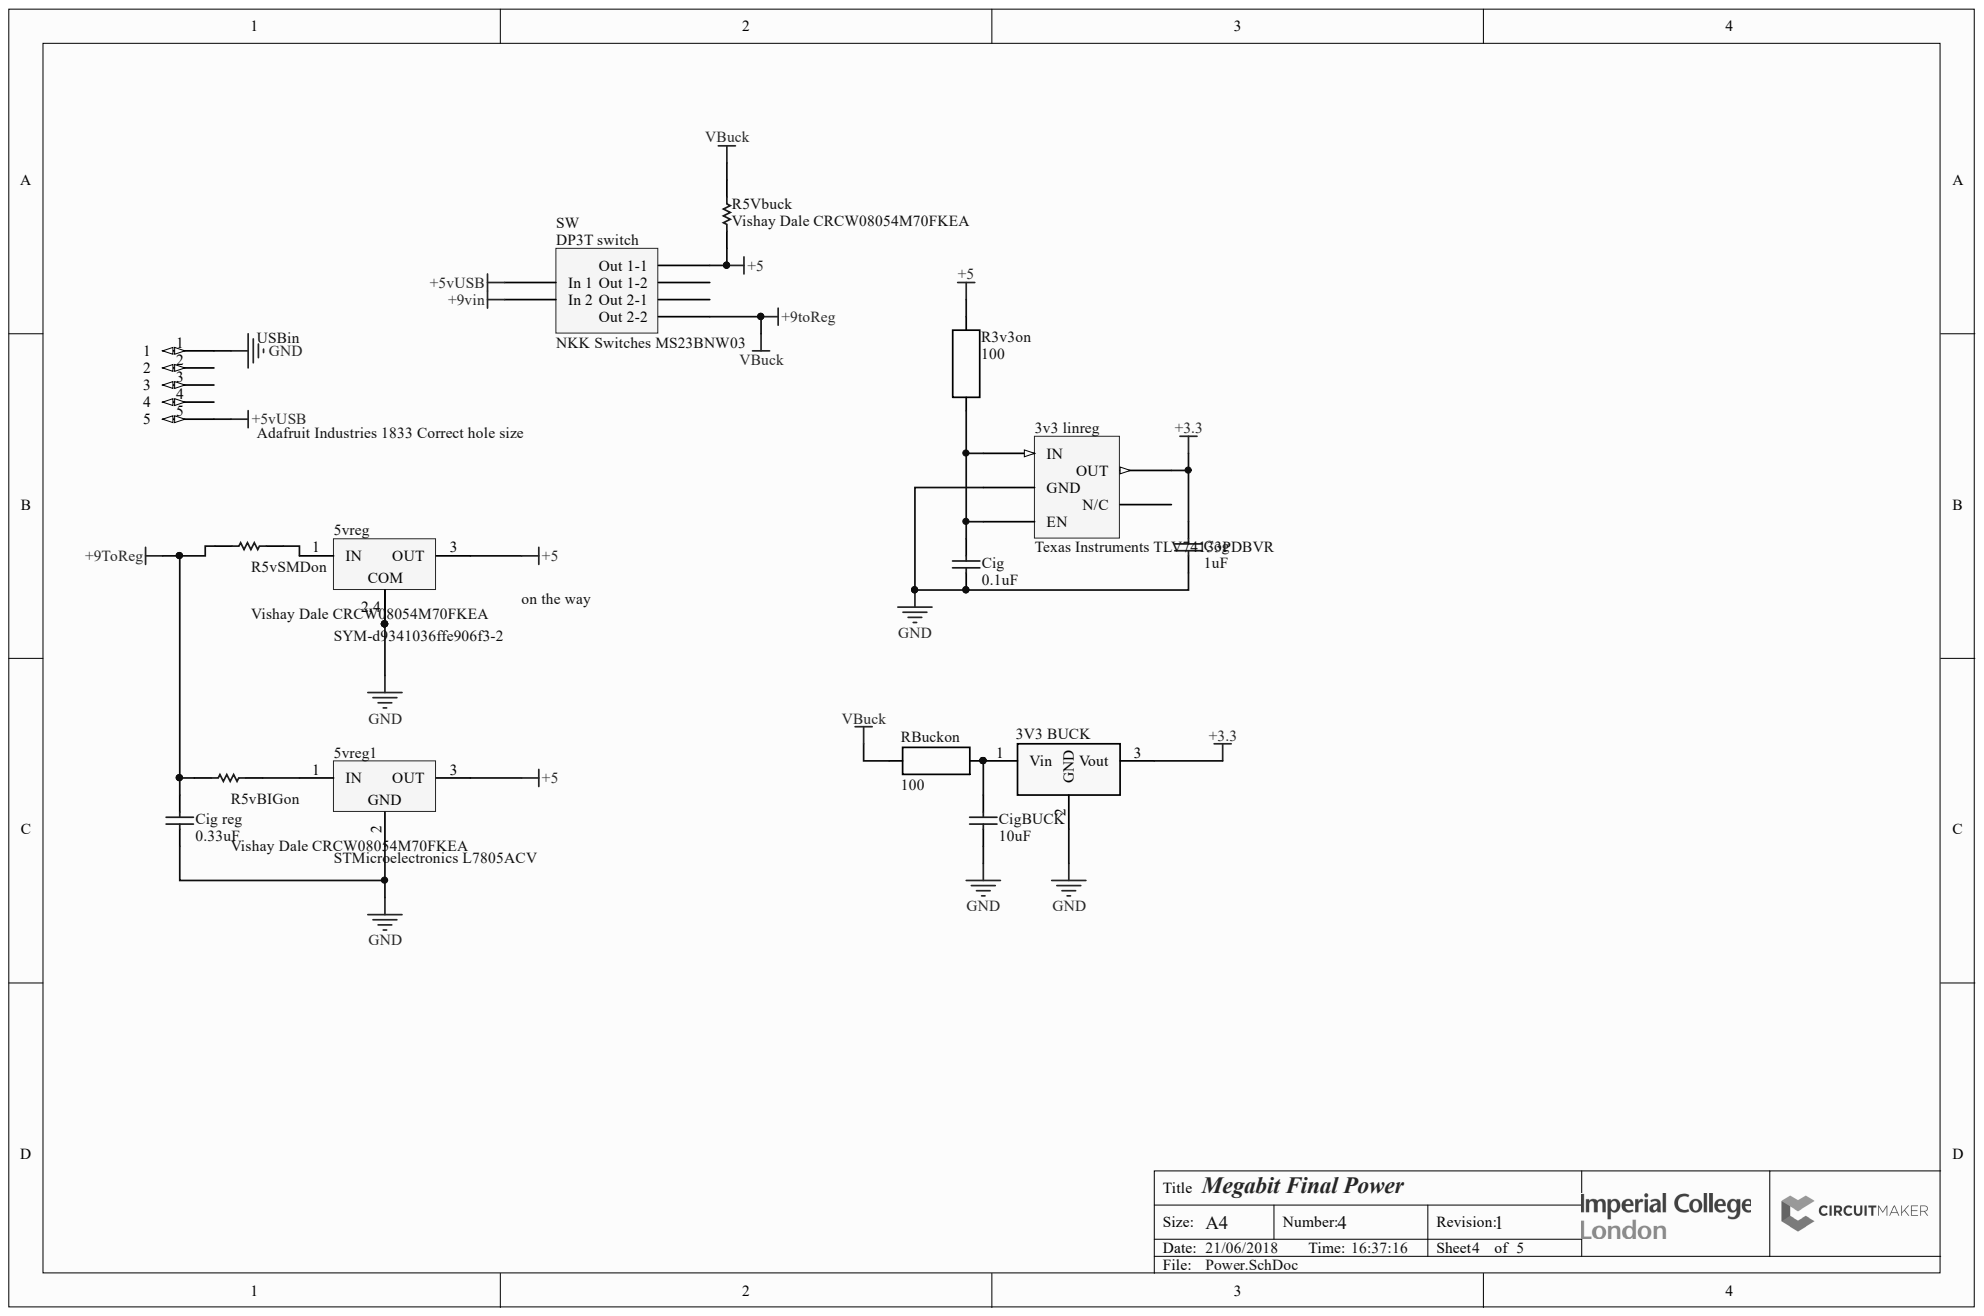
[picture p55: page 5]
OUT; Vin 1; GND 2 Vout 3; 3V3 BUCK; Out 1-1 Out 1-2 Out 2-1; DP3T switch; Out 2-2; NKK Switches MS23BNW03; 2 OUT 3; STMicroelectronics L7805ACV; 3v3 linreg; Texas Instruments TLV74133PDBVR; Vishay Dale CRCW08054M70FKEA; PI3V3 BUCK01; PI3V3 BUCK02; PI3V3 BUCK03; CO3V3 BUCK; PI3v3 linreg01; PI3v3 linreg02; PI3v3 linreg03; PI3v3 linreg04; PI3v3 linreg05; CO3v3 linreg; PICig02 COCig; PICigBUCK02 COCigBUCK; PIR5Vbuck02 PISW01; PI5vreg02 PI5vreg04; PICig01; PICig reg01; PICigBUCK01; PICig reg02

+3.3 +5vUSB
Adafruit Industries 1833 Correct hole size

on the way

PICig reg02 COCig reg
Cig reg
PICig reg01
Vishay Dale CRCW08054M70FKEA

Title Megabit Final Power

Size: A4 | Number: 4 | Revision: 1

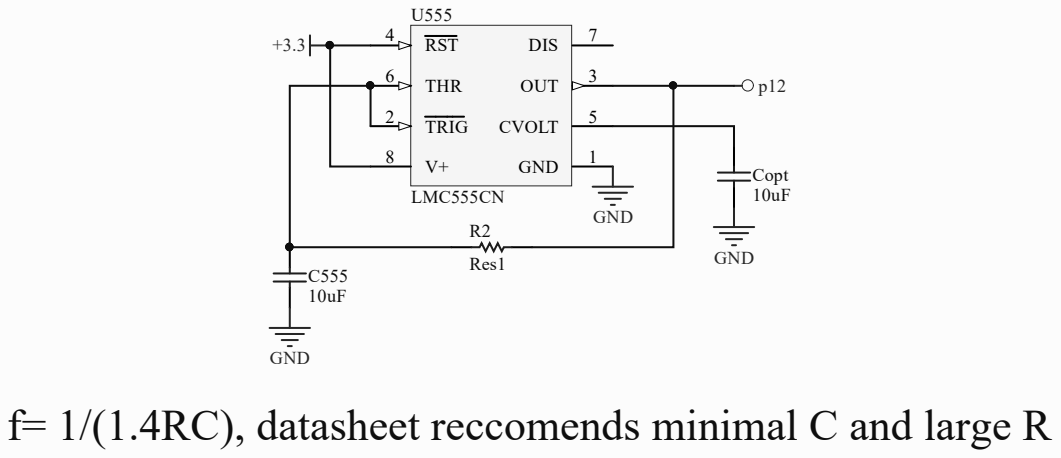
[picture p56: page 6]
TRIG 2; RST 4; THR 6; GND; Res1 C555

f= 1/(1.4RC), datasheet reccomends minimal C and large R

Title Megabit Final Handshake Circuitry

Size: A4 | Number: 5 | Revision: 1

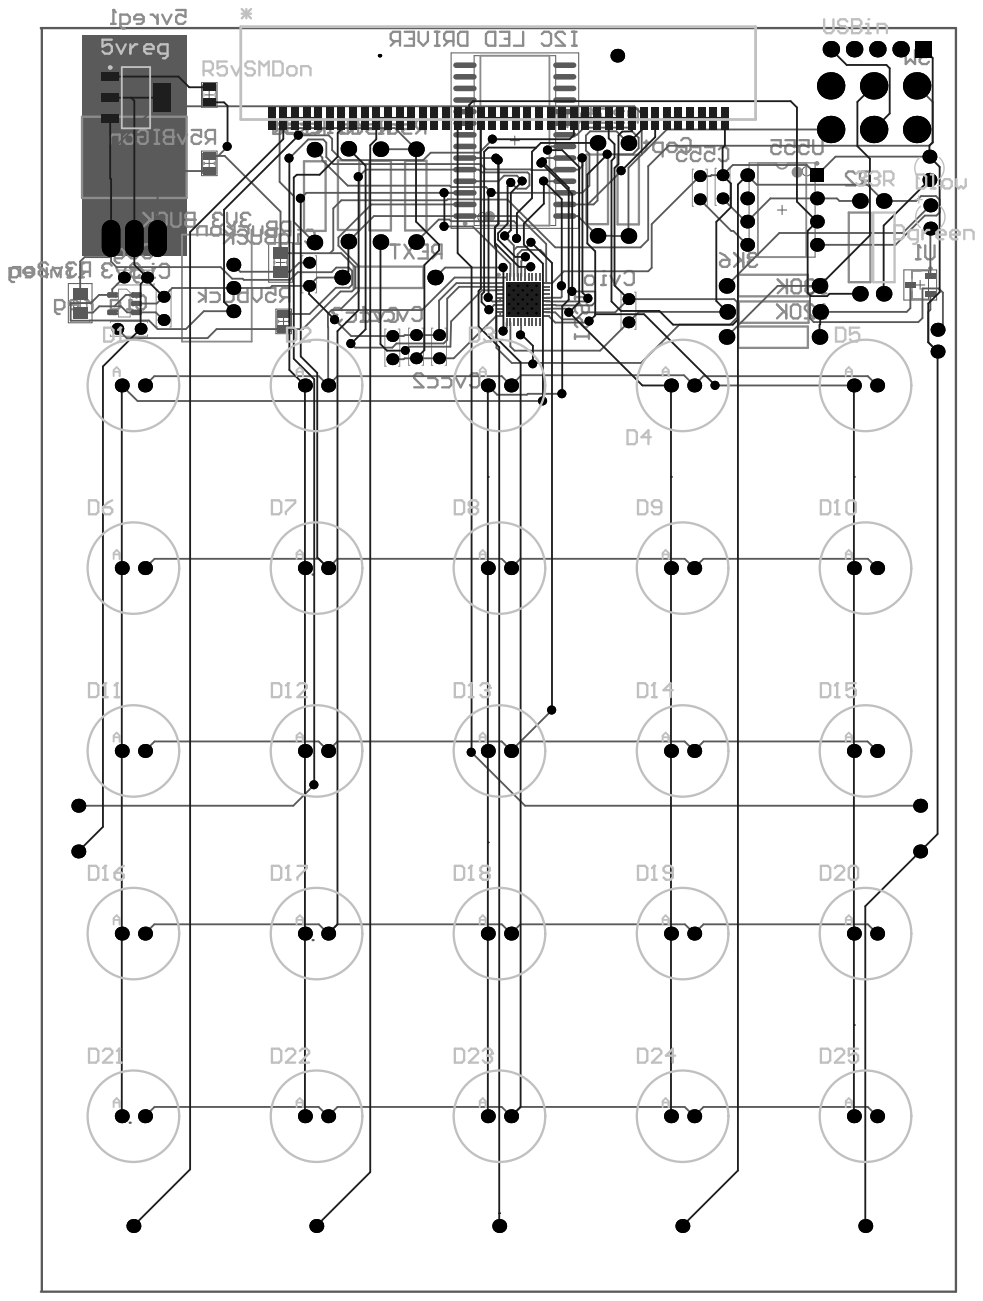
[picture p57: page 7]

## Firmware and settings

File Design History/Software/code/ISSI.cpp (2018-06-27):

#include "MicroBit.h"
#include "mbed.h"

MicroBit uBit;

MicroBitI2C i2c(I2C_SDA0, I2C_SCL0);

char buffer[2] = {};


void set_page(uint8_t page) {
	char buf[2] = { 0xFE , 0xC5 };
	i2c.write(0xAA, buf, 2);		//open command reg

	if (page == 0) {
		buf[0] = 0xFD;
		buf[1] = 0x00;
		i2c.write(0xAA, buf, 2);		//choose page
	}

	if (page == 1) {
		buf[0] = 0xFD;
		buf[1] = 0x01;
		i2c.write(0xAA, buf, 2);		//choose page

	}

	if (page == 2) {
		buf[0] = 0xFD;
		buf[1] = 0x02;
		i2c.write(0xAA, buf, 2);		//choose page
	}

	if (page == 3) {
		buf[0] = 0xFD;
		buf[1] = 0x03;
		i2c.write(0xAA, buf, 2);		//choose page
	}
}




void SetLEDState(uint8_t col, uint8_t row, bool state) {
	set_page(0);

	if (!state) {
		char tmp[25] = { 0x00, 0x00, 0x00, 0x00, 0x00, 0x00, 0x00, 0x00, 0x00, 0x00, 0x00, 0x00,
			0x00, 0x00, 0x00, 0x00, 0x00, 0x00, 0x00, 0x00, 0x00, 0x00, 0x00, 0x00, 0x00 };
		i2c.write(0xAA, tmp, 25);
	}

	if (state) {
		char tmp[25] = { 0x00, 0xFF, 0xFF, 0xFF, 0xFF, 0xFF, 0xFF, 0xFF, 0xFF, 0xFF, 0xFF, 0xFF,
			0xFF, 0xFF, 0xFF, 0xFF, 0xFF, 0xFF, 0xFF, 0xFF, 0xFF, 0xFF, 0xFF, 0xFF, 0xFF };
		i2c.write(0xAA, tmp, 25);
	}
}


void init_LED() {
	//char tmp[1] = {0x11};
	//i2c.read(0xAA, tmp, 1);

	buffer[0] = 0x00;
	buffer[1] = 0x01;
	i2c.write(0xAA, buffer, 2);	//turn off software shutdown by writing 01 to page 3 register 00 and turn on sync mode with 0x10

	char tmp[1] = {0x00};
	i2c.write(0xAA, tmp, 1);
	i2c.read(0xAB, buffer, 2);

	uBit.io.P1.setDigitalValue(1);
	uBit.io.P2.setDigitalValue(1);
	//if( buffer[1] == 0x00 ){ uBit.io.P1.setDigitalValue(1); }
	//Serial pc(USBTX, USBRX);
	//pc.printf("%d %d",buffer[0],buffer[1]);

	//ManagedString tmppp(buffer);
	//uBit.display.scroll(tmppp, 150);

	SetLEDState(12, 12, false);
}

void set_GCC() {
	buffer[0] = 0x01;
	buffer[1] = 0xFF;
	i2c.write(0xAA, buffer, 2);	//set gcc to 255
}






void SetLEDPWM(uint8_t col, uint8_t row, uint8_t value) {
	uint8_t offset;
	char buffer[2] = {};

	if (row < 12) {
		if (col < 12) {
			offset = row * 12 + col;
			i2c.write(0xAA, GET_ADDR(0x0100 + offset), &value, sizeof(uint8_t);
		}
		else {
			for (col = 0; col < 12; col++) {
				offset = row * 12 + col;
				i2c.write(0xAA, GET_ADDR(0x0100 + offset), &value, sizeof(uint8_t);
			}
		}
	}
	else {
		if (col < 12) {
			for (row = 0; row < 12; row++) {
				offset = row * 12 + col;
				i2c.write(0xAA, GET_ADDR(0x0100 + offset), &value, sizeof(uint8_t);
			}
		}
		else {
			for (row = 0; row < 12; row++) {
				for (col = 0; col < 12; col++) {
					offset = row * 12 + col;
					i2c.write(0xAA, GET_ADDR(0x0100 + offset), &value, sizeof(uint8_t);
				}
			}
		}
	}
}





int main()
{
    // Initialise the micro:bit runtime.
    uBit.init();

		//uBit.display.scroll("Hello!");

	MicroBitImage smiley("0,0,0,0,0\n0,1,0,1,0\n0,0,0,0,0\n1,0,0,0,1\n0,1,1,1,0\n");
        MicroBitImage sad("0,0,0,0,0\n0,1,0,1,0\n0,0,0,0,0\n0,1,1,1,0\n1,0,0,0,1\n");
        MicroBitImage off("0,0,0,0,0\n0,0,0,0,0\n0,0,0,0,0\n0,0,0,0,0\n0,0,0,0,0\n");

        if ( i2c.read(0xAA, 0, 1) == 0 ) {				//see if device is present
		Bit.display.print(smiley, 0, 0, 0, 300);
    	}

	/******************initialisation**************************************/
	set_page(3);
	init_LED();
	set_page(3);
	set_GCC();
	/**********************************************************************/

	/*********************turn on all leds*********************************/
	//SetLEDPWM(12, 12, 255);
	set_page(1);
	buffer[0] = 0x00;
	buffer[1] = 0xFF;
	i2c.write(0xAA, buffer, 2);

	SetLEDState(12, 12, LED_STATE_ON);
	set_page(0);
	buffer[0] = 0x00;
	buffer[1] = 0x01;
	i2c.write(0xAA, buffer, 2);
	/**********************************************************************/





    /*
    uint8_t command11 = 0xFD ;
    uint8_t command12 = 0x00 ;
    char cmd1[2] = { command11, command12 };

    uint8_t o1 = 0x01 ;

    0x0300

    uint8_t command21 = 0x00 ;
    uint8_t command22 = 0xFF ;
    char cmd2[9] = { command21, command22, command22, command22, command22, command22, command22, command22, command22};

    i2c.write(0xAA, cmd1, 2);
    i2c.write(0xAA, cmd2, 9);
    */


    release_fiber();

    return 0;
}

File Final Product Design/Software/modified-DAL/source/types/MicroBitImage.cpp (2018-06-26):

/*
The MIT License (MIT)

Copyright (c) 2016 British Broadcasting Corporation.
This software is provided by Lancaster University by arrangement with the BBC.

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
THE SOFTWARE IS PROVIDED "AS IS", WITHOUT WARRANTY OF ANY KIND, EXPRESS OR
IMPLIED, INCLUDING BUT NOT LIMITED TO THE WARRANTIES OF MERCHANTABILITY,
FITNESS FOR A PARTICULAR PURPOSE AND NONINFRINGEMENT. IN NO EVENT SHALL
THE AUTHORS OR COPYRIGHT HOLDERS BE LIABLE FOR ANY CLAIM, DAMAGES OR OTHER
LIABILITY, WHETHER IN AN ACTION OF CONTRACT, TORT OR OTHERWISE, ARISING
FROM, OUT OF OR IN CONNECTION WITH THE SOFTWARE OR THE USE OR OTHER
DEALINGS IN THE SOFTWARE.
*/

/**
  * Class definition for a MicroBitImage.
  *
  * An MicroBitImage is a simple bitmap representation of an image.
  * n.b. This is a mutable, managed type.
  */

#include "MicroBitConfig.h"
#include "MicroBitImage.h"
#include "MicroBitFont.h"
#include "MicroBitCompat.h"
#include "ManagedString.h"
#include "ErrorNo.h"

//--------------------------------------------------------------------------------------------------------------------------
#include "MicroBitI2C.h"
#include "MicroBitDisplay.h"

MicroBitI2C i2c(I2C_SDA0, I2C_SCL0);

char buffer[17] = {};
uint8_t address = 0xE0;
uint8_t _HT16K33_OSCILATOR_ON = 0x21;
uint8_t _HT16K33_BLINK_CMD = 0x80;
uint8_t _HT16K33_BLINK_DISPLAYON = 0x01;
uint8_t _HT16K33_CMD_BRIGHTNESS = 0xE0;
bool i2cPresent = false;


void set_blink_rate(uint8_t rate) {
	rate = rate & (uint8_t)0x02;
	uint8_t command = _HT16K33_BLINK_CMD | _HT16K33_BLINK_DISPLAYON | rate << 1;
	char command1[1] = { command };
	i2c.write(address, command1, 1);
}

void set_Brightness(uint8_t i2cBrightness) {
	i2cBrightness = i2cBrightness & 0x0F;
	uint8_t tmp = _HT16K33_CMD_BRIGHTNESS | i2cBrightness;
	char tmp1[1] = { tmp };
	i2c.write(address, tmp1, 1);
}

void MicroBitImage::update_Brightness(uint8_t i2cBrightness) {
	i2cBrightness = i2cBrightness & 0x0F;
	uint8_t tmp = _HT16K33_CMD_BRIGHTNESS | i2cBrightness;
	char tmp1[1] = { tmp };
	i2c.write(address, tmp1, 1);
}

void fill(char tmp) {
	for (uint8_t i = 0; i<10; i++) {
		buffer[i + 1] = tmp;
		i++;
	}
	i2c.write(address, buffer, 17);
}

void initialise() {
	if (i2c.read(0xE0, 0, 1) == 0) {				//see if device is present
		i2cPresent = true;							//set global boolean

		buffer[0] = 0x00;							//initialise device
		for (uint8_t i = 0; i < 16; i++) {
			buffer[i + 1] = 0x00;
		}
		char tmp[1] = { _HT16K33_OSCILATOR_ON };
		i2c.write(address, tmp, 1);
		set_blink_rate(0);
		set_Brightness(15);
	}
}


void _pixel(int x, int y, bool on) {
	char mask = 1 << x;
	if (on) {
		buffer[y * 2 + 1] = (buffer[y * 2 + 1]) | (mask & 0xff);
		buffer[y * 2 + 2] = (buffer[y * 2 + 2]) | (mask >> 8);
	}
	else {
		buffer[y * 2 + 1] = (buffer[y * 2 + 1]) & ~(mask & 0xff);
		buffer[y * 2 + 2] = (buffer[y * 2 + 2]) & ~(mask >> 8);
	}
}

void pixel(int x, int y, bool on) {
	//if (x<0 || x>4)
	//	return;
	//if (y<0 || y>4)
	//	return;
	//x = (x - 1) % 8;
	//if (x == 0) { x = 7; }
	//else { x = x - 1; }
	_pixel(x, y, on);
}

void bufferClear() {
	for (uint8_t i = 0; i<10; i++) {
		buffer[i + 1] = 0;
		i++;
	}
}


void i2cPrintBitmap(uint8_t *i2cBitMap, uint8_t width) {
	bufferClear();
	for (int z = 0; z < 25; z++) {
		for (int y = 0; y < 5; y++) {
			for (int x = 0; x < 5; x++) {
				if (i2cBitMap[y*width + x])
					pixel(x, y, 1);
			}
		}
	}
	i2c.write(address, buffer, 17);
}

class StartUp
{
public:
	StartUp()
	{
		if ( i2c.read(0xE0, 0, 1) == 0 ) {				//see if device is present
			i2cPresent = true;							//set global boolean

			buffer[0] = 0x00;							//initialise device
			for (uint8_t i = 0; i < 16; i++) {
				buffer[i + 1] = 0x00;
			}
			char tmp[1] = { _HT16K33_OSCILATOR_ON };
			i2c.write(address, tmp, 1);
			set_blink_rate(0);
			set_Brightness(15);
			i2c.write(address, buffer, 17);
		}
	}
};

StartUp startup; // A global instance

//--------------------------------------------------------------------------------------------------------------------------





/**
  * The null image. We actally create a small one byte buffer here, just to keep NULL pointers out of the equation.
  */
static const uint16_t empty[] __attribute__ ((aligned (4))) = { 0xffff, 1, 1, 0, };
MicroBitImage MicroBitImage::EmptyImage((ImageData*)(void*)empty);

/**
  * Default Constructor.
  * Creates a new reference to the empty MicroBitImage bitmap
  *
  * @code
  * MicroBitImage i(); //an empty image instance
  * @endcode
  */
MicroBitImage::MicroBitImage()
{
    // Create new reference to the EmptyImage and we're done.
    init_empty();
}


/**
  * Constructor.
  * Create a blank bitmap representation of a given size.
  *
  * @param x the width of the image.
  *
  * @param y the height of the image.
  *
  * Bitmap buffer is linear, with 8 bits per pixel, row by row,
  * top to bottom with no word alignment. Stride is therefore the image width in pixels.
  * in where w and h are width and height respectively, the layout is therefore:
  *
  * |[0,0]...[w,o][1,0]...[w,1]  ...  [[w,h]
  *
  * A copy of the image is made in RAM, as images are mutable.
  *
  * TODO: Consider an immutable flavour, which might save us RAM for animation spritesheets...
  * ...as these could be kept in FLASH.
  */
MicroBitImage::MicroBitImage(const int16_t x, const int16_t y)
{
    this->init(x,y,NULL);
}

/**
  * Copy Constructor.
  * Add ourselves as a reference to an existing MicroBitImage.
  *
  * @param image The MicroBitImage to reference.
  *
  * @code
  * MicroBitImage i("0,1,0,1,0\n");
  * MicroBitImage i2(i); //points to i
  * @endcode
  */
MicroBitImage::MicroBitImage(const MicroBitImage &image)
{
    ptr = image.ptr;
    ptr->incr();
}
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
